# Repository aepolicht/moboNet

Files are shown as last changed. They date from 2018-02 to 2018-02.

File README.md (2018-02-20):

moboNet
=======

  This repo is a collection of elements contributing to one home automation project. It consists of analysis, schematics,
and software.

Notes
=====

Version 0.0.1
	Added Features:
		-Recall previous state from memory using EEPROM

	Bug Fixes:
		-Remove Flashes when receiving message

Version 0.0.2
	Added Features:
		-All communication now shall be over UDP packets

Version 0.0.3
	Changes:
		-Added notifications features to all devices
		-Added basic music detection and visualization code
			-Changes were also made to the hardware side of the music detection.
			 The low pass filter desired seems to have a cutoff right at 220 Hz.
		 	 Ideally this simple filter will consist of a 1 uF capacitor and a
		 	 7.5 kOhm resistor.
		-Implemented serial connection to bulb array to communicate with display 
		 projection from PC. Currently it checks serial, then homenet for any input
		 but if this proves to slow down the projection too much i may need a blocking
		 version where when serial is inbound all other code is ignored.
		-Changed to "FastSPI" library for communication with WS2801 LED strings
			-Also tried out an Adafruit library for this purpose but i found that
			 that library was blocking and took significantly more time to run
			 than the FastSPI library took.
			-FastSPI is non-blocking and takes around 300 uS to finish its write
		     otherwise overwriting while in progress produces undesirable effects.
	    -Implemented notifications for door knock however the whole system needs an
	     overhaul to simplify the process of [alarm device]->[base station]->[bulb clients]
	    -Implemented code for the door knock detector notifier.
	    
Version 0.0.4
	Note:
		I have begun to implement the music detection system. The basis for the whole system
		is contingent upon the frequency response of the low pass filter. I have chosen a simple
		filter with passband edge around 300 Hz. In this design a large gap between the passband 
		and the stop-band is desired because of how i plan to implement the software side of the
		music detection. Here is a rough graph of the frequency response:

			                    |H(w)| for LPF (1st order fc = 300Hz)
					  (dB)
					 0	|x x x x x x x x x x x 
					 	|                      x 
					-5	|                        x 
						|                          x
					-10	|                            x
						|                              x              
					-15	|                                x               
						|                                  x         
					-20	|                                    x           
						|                                      x         
					-25	|                                        x            
						|                                          x              
					-30	|                                            x                  
						|                                              x      
					-35	|                                                x      
						-------|----------|-----------|------------|----- Hz (log)
						0     10         100        1000         10000   

		The basis for the software side is having an understanding of the filters response
		and using this to determine whether or not the input signal is a Low, Mid or High.
		I am doing it this way to avoid any additional circuitry because i want a small
		package. It is easiest to detect the beat and very low frequencies because these are
		the largest in magnitude. I want a large gap between the passband and stop-band edges
		because i want to be able to detect other frequencies at attenuated magnitudes.
		To overcome the problem of detecting loud mids as a bass and other situations, i take
		an average of the last 64 samples as a reference. Given that reference the respective
		frequencies will then be function of the average unique to those frequency bands. To
		obtain a reference i sampled the desired frequency at different volumes IE different 
		values of the variable "ave". I then applied best fit lines and use them as cutoffs
		to determine which band a sample should be classified to. The best fits i have found
		are:
 
			Lows  (0-230Hz)   Threshold = 67*log(ave-1)-10
			Mids  (230-800Hz) Threshold = 25*log(ave-1)-5
			Highs (800+Hz)    Threshold = 12*log(ave-1)-5

		It is much more difficult to detect a high with this filter because signals higher than 
		800 Hz are attenuated more severely beginning with 800 Hz at -9 dB. The other method for
		doing this type of thing would be with a ~6000 Hz lpf and performing an FFT which i will
		do to see if its viable given the constraints.

		My preliminary DFT implementation with a 128 sample input and no special windowing takes around 2.5 seconds per DFT which is much too long. When N is 32, it takes about 155 mS.
		This would mean a sampling rate of T > 155 mS which a sampling frequency of less than
		6 Hz which is pretty much useless. The to attain a Nyquist frequency of a signal of 2000 Hz
		i need to have a sampling frequency of 4000 Hz which means the DFT finish in <250 uS. I 
		have found an FFT library for Arduino but it takes more than 600 uS to complete the FFT.
		This means i will continue with my previous method of implementing the lump spectral
		analysis.

TBD:
x-Add days support to android
x-Redesign notifications so that they are handled by base station
o-Setup music mode on all devices
x-Setup Door knock codes for base station and knocker
o-Setup Ambiance mode
o-Fix Android save and return functionality
o-Finish C# desktop application
o-Add notification options to base station and android options menu
o-Implement Groups on all devices

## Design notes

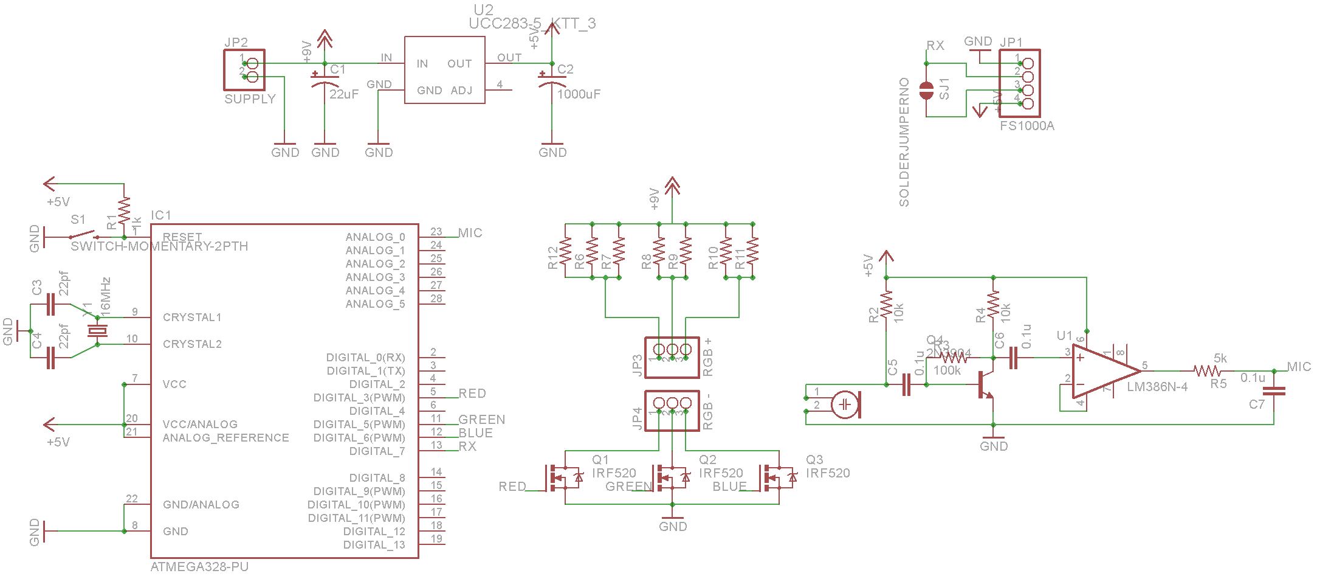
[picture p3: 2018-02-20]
Bulb_Node_PCB/Due/Schematic.png

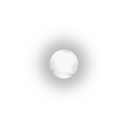
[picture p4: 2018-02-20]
PC_Application_Master Control/Master Control/Properties/Resources/Blank.png

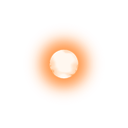
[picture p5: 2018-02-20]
PC_Application_Master Control/Master Control/Resources/Orange.png

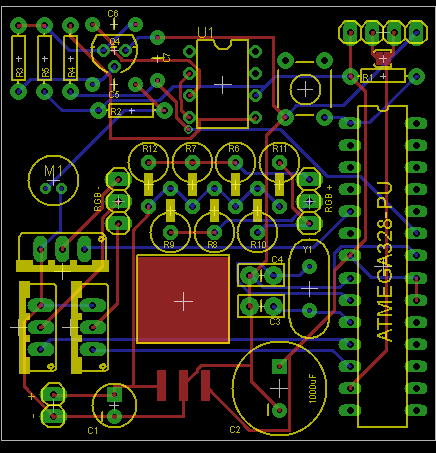
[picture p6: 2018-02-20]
Bulb_Node_PCB/Due/PCB2.png

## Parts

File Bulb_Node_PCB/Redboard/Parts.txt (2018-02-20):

Partlist

Exported from RedBoard-v21.sch at 2/24/2015 8:32:50 PM

EAGLE Version 7.1.0 Copyright (c) 1988-2014 CadSoft

Assembly variant: 

Part     Value                             Device                            Package                                Library               Sheet

AD                                         M06SMD-STRAIGHT-COMBO             1X06_SMD_STRAIGHT_COMBO                SparkFun              1
C1       0.1uF                             CAP0603-CAP                       0603-CAP                               SparkFun              1
C2       0.1uF                             CAP0603-CAP                       0603-CAP                               SparkFun              1
C3       10uF                              CAP_POL1206                       EIA3216                                SparkFun              1
C4       0.1uF                             CAP0603-CAP                       0603-CAP                               SparkFun              1
C5       47uF                              CAP_POLD                          PANASONIC_D                            SparkFun              1
C6       10uF                              CAP_POL1206                       EIA3216                                SparkFun              1
C7       1uF                               CAP0603-CAP                       0603-CAP                               SparkFun              1
C8       0.1uF                             CAP0603-CAP                       0603-CAP                               SparkFun              1
C9       47pF                              47PF-50V-5%(0603)                 0603-CAP                               SparkFun-Capacitors   1
C10      0.1uF                             CAP0603-CAP                       0603-CAP                               SparkFun              1
C12      0.1uF                             CAP0603-CAP                       0603-CAP                               SparkFun              1
C13      47pF                              47PF-50V-5%(0603)                 0603-CAP                               SparkFun-Capacitors   1
C14      0.1uF                             CAP0603-CAP                       0603-CAP                               SparkFun              1
C15      10uF                              CAP_POL1206                       EIA3216                                SparkFun-Capacitors   1
D1       MBRA140                           DIODE-SCHOTTKY_                   SMA-DIODE                              SparkFun              1
F1       500mA                             PTCSMD                            PTC-1206                               SparkFun              1
IC3      LM1117                            V_REG_LM1117ALT1                  SOT223-ALT1                            Testing               1
IOL                                        M08SMD-COMBO                      1X08_SMD_COMBINED                      SparkFun              1
J1       POWER_JACKOVERPASTE_REDBOARD_0603 POWER_JACKOVERPASTE_REDBOARD_0603 POWER_JACK_SMD_OVERPASTE_REDBOARD_0603 Testing               1
J2       ICSP                              AVR_SPI_PRG_6SMT_MALE             2X3_SMT_POSTS                          SparkFun-Connectors   1
JP2      M10SMD_COMBO                      M10SMD_COMBO                      1X10_SMD_COMBINED                      SparkFun-Connectors   1
JP10                                       M08SMD-COMBO                      1X08_SMD_COMBINED                      SparkFun-Connectors   1
LED1     Blue                              LED1206-NS                        LED-1206-NO_SILK                       SparkFun-LED          1
LED2     Green                             LED1206-NS                        LED-1206-NO_SILK                       SparkFun-LED          1
LED3     Red                               LED1206-NS                        LED-1206-NO_SILK                       SparkFun-LED          1
LED4     Yellow                            LED1206-NS                        LED-1206-NO_SILK                       SparkFun-LED          1
Q1       ZXMP6A13FTA                       MOSFET-PCHANNELSMD                SOT23-3                                SparkFun              1
Q2       2N7002PW                          MOSFET-NCHANNEL2N7002PW           SOT323                                 SparkFun-DiscreteSemi 1
R1       1k                                RESISTOR0603-RES                  0603-RES                               SparkFun              1
R2       1k                                RESISTOR0603-RES                  0603-RES                               SparkFun              1
R3       10k                               RESISTOR0603-RES                  0603-RES                               SparkFun              1
R4       10k                               RESISTOR0603-RES                  0603-RES                               SparkFun              1
R5       27                                RESISTOR0603-RES                  0603-RES                               SparkFun-Resistors    1
R6       1k                                RESISTOR0603-RES                  0603-RES                               SparkFun              1
R7       1k                                RESISTOR0603-RES                  0603-RES                               SparkFun              1
R8       1k                                RESISTOR0603-RES                  0603-RES                               SparkFun              1
R9       1k                                RESISTOR0603-RES                  0603-RES                               SparkFun              1
R10      27                                RESISTOR0603-RES                  0603-RES                               SparkFun-Resistors    1
R11      10k                               RESISTOR0603-RES                  0603-RES                               SparkFun              1
R12      10k                               RESISTOR0603-RES                  0603-RES                               SparkFun              1
R14      715                               RESISTOR0603-RES                  0603-RES                               SparkFun              1
R15      240                               RESISTOR0603-RES                  0603-RES                               SparkFun              1
S1       RESET                             TAC_SWITCHSMD                     TACTILE_SWITCH_SMD                     SparkFun              1
TP1      TP-3x5                            TEST-POINT3X5                     PAD.03X.05                             SparkFun-Passives     1
TP2      TP-3x5                            TEST-POINT3X5                     PAD.03X.05                             SparkFun-Passives     1
TP3      TP-3x5                            TEST-POINT3X5                     PAD.03X.05                             SparkFun-Passives     1
TP4      TP-3x5                            TEST-POINT3X5                     PAD.03X.05                             SparkFun-Passives     1
TP5      TP-3x5                            TEST-POINT3X5                     PAD.03X.05                             SparkFun-Passives     1
TP6      TP-3x5                            TEST-POINT3X5                     PAD.03X.05                             SparkFun-Passives     1
U$13     USB-MINIB-5PIN                    USB-MINIB-5PIN                    USB-MINIB                              SparkFun-Connectors   1
U1       FT231XS                           FT231XS                           SSOP20_L                               SparkFun-DigitalIC    1
U2       MIC5205                           V_REG_LDOSMD                      SOT23-5                                SparkFun              1
U3       ATMEGA328                         ATMEGA168                         TQFP32-08                              SparkFun              1
Y1       16MHz                             RESONATORSMD                      RESONATOR-SMD                          SparkFun-FreqCtrl     1

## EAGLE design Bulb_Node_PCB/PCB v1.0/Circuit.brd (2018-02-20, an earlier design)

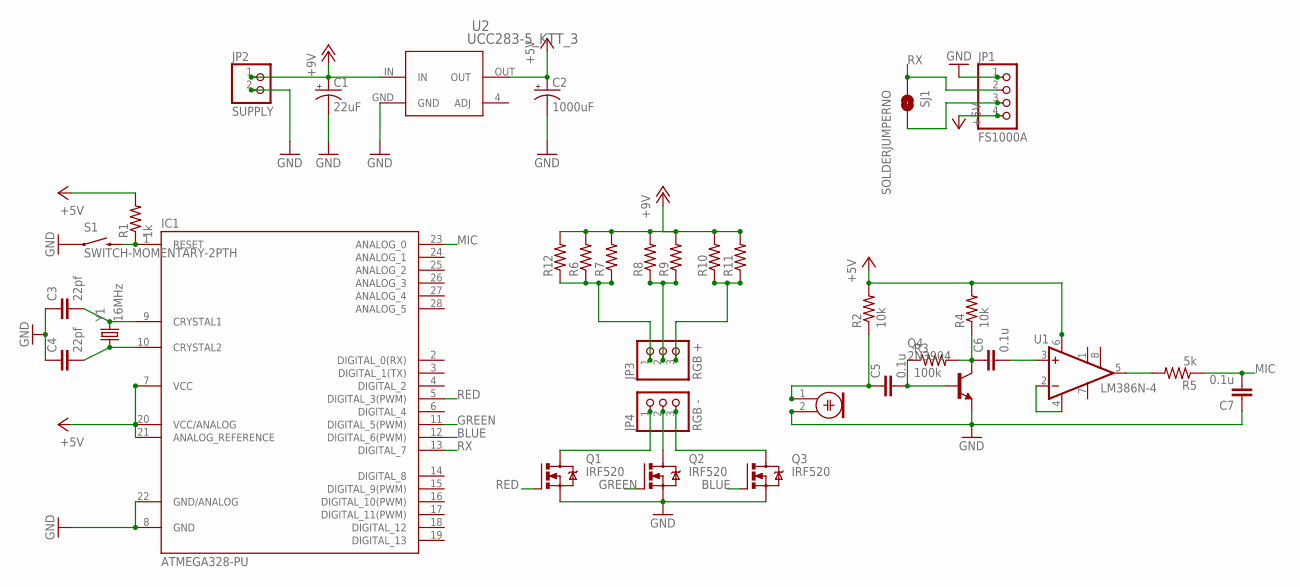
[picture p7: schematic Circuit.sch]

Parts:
C1: 22uF; CPOL-RADIAL-10UF-25V
C2: 1000uF; CPOL-RADIAL-1000UF-25V
C3, C4: 22pf; CAP-PTH-SMALL-KIT
C5, C6, C7: 0.1u; CAP-PTH-5MM
IC1: ATMEGA328-PU; DIL28-3
JP1: FS1000A; 1X04
JP2: SUPPLY; 1X02
JP3: RGB +; 1X03
JP4: RGB -; 1X03
M1: MIC; WM-62PC/62PK
Q1, Q2, Q3: IRF520; TO220BV
Q4: 2N3904; TO92
R1: 1k; AXIAL-0.3EZ
R2, R4: 10k; AXIAL-0.3EZ
R3: 100k; AXIAL-0.3EZ
R5: 5k; AXIAL-0.3EZ
R6, R7, R8, R9, R10, R11, R12: R-US_0613/5V; P0613V
S1: SWITCH-MOMENTARY-2PTH; TACTILE-PTH
SJ1: SOLDERJUMPERNO; SJ_2S-NO
U1: LM386N-4; DIL08
U2: UCC283-5_KTT_3; KTT3_6P22X6P6
Y1: 16MHz; HC49US

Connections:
+5V: C2.1 (+), IC1.7 (VCC), IC1.20 (VCC/ANALOG), IC1.21 (ANALOG_REFERENCE), JP1.4, R1.P$2 (2), R2.P$2 (2), R4.P$2 (2), U1.6 (VS), U2.OUT
+12V: C1.1 (+), JP2.1, R6.2, R7.2, R8.2, R9.2, R10.2, R11.2, R12.2, U2.IN
BLUE: IC1.12 (DIGITAL_6(PWM)), Q3.G
GND: C1.2 (-), C2.2 (-), C3.1, C4.1, C7.1, IC1.8 (GND), IC1.22 (GND/ANALOG), JP1.1, JP2.2, M1.2, Q1.S, Q2.S, Q3.S, Q4.3 (E), S1.1, U2.GND
GREEN: IC1.11 (DIGITAL_5(PWM)), Q2.G
MIC: C7.2, IC1.23 (ANALOG_0), R5.P$1 (1)
unnamed: JP1.3, SJ1.2
unnamed: C3.2, IC1.9 (CRYSTAL1), Y1.2
unnamed: C4.2, IC1.10 (CRYSTAL2), Y1.1
unnamed: IC1.1 (RESET), R1.P$1 (1), S1.3 (2)
unnamed: JP4.1, Q1.D
unnamed: JP4.2, Q2.D
unnamed: JP4.3, Q3.D
unnamed: C5.2, Q4.2 (B), R3.P$1 (1)
unnamed: C5.1, M1.1, R2.P$1 (1)
unnamed: C6.1, Q4.1 (C), R3.P$2 (2), R4.P$1 (1)
unnamed: R5.P$2 (2), U1.5 (OUT)
unnamed: U1.2 (-IN), U1.4 (GND)
unnamed: JP3.1, R6.1, R7.1, R12.1
unnamed: JP3.2, R8.1, R9.1
unnamed: JP3.3, R10.1, R11.1
unnamed: C6.2, U1.3 (+IN)
RED: IC1.5 (DIGITAL_3(PWM)), Q1.G
RX: IC1.13 (DIGITAL_7), JP1.2, SJ1.1

Board: 2 copper layers, 34 parts (0 on the bottom side), 24 nets, no tracks yet.

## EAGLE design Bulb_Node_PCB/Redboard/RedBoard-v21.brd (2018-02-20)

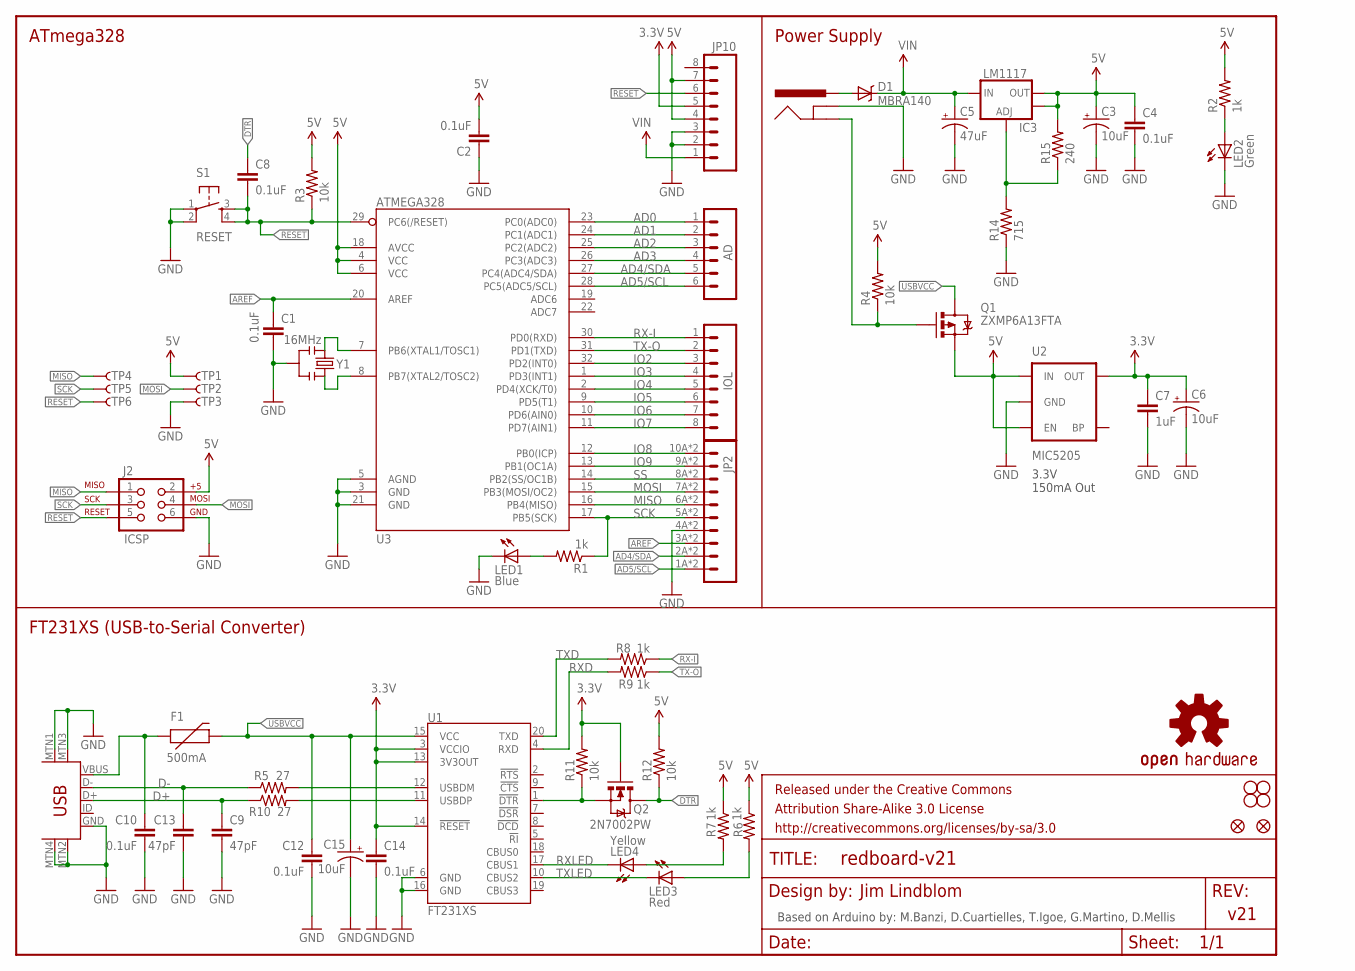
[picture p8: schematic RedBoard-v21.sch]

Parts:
AD: M06SMD-STRAIGHT-COMBO; 1X06_SMD_STRAIGHT_COMBO
C1, C2, C4, C8, C10, C12, C14: 0.1uF; 0603-CAP
C3, C6, C15: 10uF; EIA3216
C5: 47uF; PANASONIC_D
C7: 1uF; 0603-CAP
C9, C13: 47pF; 0603-CAP
D1: MBRA140; SMA-DIODE
F1: 500mA; PTC-1206
FRAME2: FRAME-LETTER; CREATIVE_COMMONS
IC3: LM1117; SOT223-ALT1
IOL: M08SMD-COMBO; 1X08_SMD_COMBINED
J1: POWER_JACKOVERPASTE_REDBOARD_0603; POWER_JACK_SMD_OVERPASTE_REDBOARD_0603
J2: ICSP; 2X3_SMT_POSTS
JP2: M10SMD_COMBO; 1X10_SMD_COMBINED
JP3, JP4, JP5, JP6: STAND-OFF
JP8, JP9: FIDUCIAL1X2; FIDUCIAL-1X2
JP10: M08SMD-COMBO; 1X08_SMD_COMBINED
LED1: Blue; LED-1206-NO_SILK
LED2: Green; LED-1206-NO_SILK
LED3: Red; LED-1206-NO_SILK
LED4: Yellow; LED-1206-NO_SILK
Q1: ZXMP6A13FTA; SOT23-3
Q2: 2N7002PW; SOT323
R1, R2, R6, R7, R8, R9: 1k; 0603-RES
R3, R4, R11, R12: 10k; 0603-RES
R5, R10: 27; 0603-RES
R14: 715; 0603-RES
R15: 240; 0603-RES
S1: RESET; TACTILE_SWITCH_SMD
TP1, TP2, TP3, TP4, TP5, TP6: TP-3x5; PAD.03X.05
U1: FT231XS; SSOP20_L
U2: MIC5205; SOT23-5
U3: ATMEGA328; TQFP32-08
U$13: USB-MINIB-5PIN; USB-MINIB
U$16: OSHW-LOGOS; OSHW-LOGO-S
Y1: 16MHz; RESONATOR-SMD

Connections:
3.3V: C6.A (+), C7.1, C14.1, JP10.5, Q2.1 (G), R11.2, U1.3 (VCCIO), U1.13 (3V3OUT), U1.14 (!RESET), U2.5 (OUT)
5V: C2.2, C3.A (+), C4.1, IC3.2 (OUT), IC3.4 (OUT), J2.2, JP10.4, JP10.7, Q1.2 (S), R2.2, R3.2, R4.2, R6.1, R7.1, R12.2, R15.2, TP1.P$1, U2.1 (IN), U2.3 (EN), U3.4 (VCC), U3.6 (VCC), U3.18 (AVCC)
AD0: AD.1, U3.23 (PC0(ADC0))
AD1: AD.2, U3.24 (PC1(ADC1))
AD2: AD.3, U3.25 (PC2(ADC2))
AD3: AD.4, U3.26 (PC3(ADC3))
AD4/SDA: AD.5, JP2.2A (2), JP2.2B (2), U3.27 (PC4(ADC4/SDA))
AD5/SCL: AD.6, JP2.1A (1), JP2.1B (1), U3.28 (PC5(ADC5/SCL))
AREF: C1.1, JP2.3A (3), JP2.3B (3), U3.20 (AREF)
D+: C9.1, R10.1, U$13.D+
D-: C13.1, R5.1, U$13.D-
DTR: C8.1, Q2.3 (D), R12.1
GND: C1.2, C2.1, C3.C (-), C4.2, C5.-, C6.C (-), C7.2, C9.2, C10.2, C12.2, C13.2, C14.2, C15.C (-), J1.GND (GNDBREAK), J2.6, JP2.4A (4), JP2.4B (4), JP10.2, JP10.3, LED1.C, LED2.C, R14.1, S1.1, S1.2, TP3.P$1, U1.6 (GND), U1.16 (GND), U2.2 (GND), U3.3 (GND), U3.5 (AGND), U3.21 (GND), U$13.GND, U$13.MTN1 (MTN2), U$13.MTN2 (MTN3), U$13.MTN3 (MTN1), U$13.MTN4, Y1.2
INSERT: J1.P$4 (GND), Q1.1 (G), R4.1
IO2: IOL.3, U3.32 (PD2(INT0))
IO3: IOL.4, U3.1 (PD3(INT1))
IO4: IOL.5, U3.2 (PD4(XCK/T0))
IO5: IOL.6, U3.9 (PD5(T1))
IO6: IOL.7, U3.10 (PD6(AIN0))
IO7: IOL.8, U3.11 (PD7(AIN1))
IO8: JP2.10A (10), JP2.10B (10), U3.12 (PB0(ICP))
IO9: JP2.9A (9), JP2.9B (9), U3.13 (PB1(OC1A))
MISO: J2.1, JP2.6A (6), JP2.6B (6), TP4.P$1, U3.16 (PB4(MISO))
MOSI: J2.4, JP2.7A (7), JP2.7B (7), TP2.P$1, U3.15 (PB3(MOSI/OC2))
unnamed: LED1.A, R1.2
unnamed: LED2.A, R2.1
unnamed: U3.7 (PB6(XTAL1/TOSC1)), Y1.1
unnamed: U3.8 (PB7(XTAL2/TOSC2)), Y1.3
unnamed: R5.2, U1.12 (USBDM)
unnamed: R10.2, U1.11 (USBDP)
unnamed: LED3.A, R6.2
unnamed: LED4.A, R7.2
unnamed: Q2.2 (S), R11.1, U1.1 (!DTR)
unnamed: IC3.1 (ADJ), R14.2, R15.1
PWRIN: D1.A, J1.VIN0 (PWR)
RESET: C8.2, J2.5, JP10.6, R3.1, S1.3, S1.4, TP6.P$1, U3.29 (PC6(/RESET))
RX-I: IOL.1, R8.1, U3.30 (PD0(RXD))
RXD: R9.2, U1.4 (RXD)
RXLED: LED4.C, U1.17 (CBUS1)
SCK: J2.3, JP2.5A (5), JP2.5B (5), R1.1, TP5.P$1, U3.17 (PB5(SCK))
SS: JP2.8A (8), JP2.8B (8), U3.14 (PB2(SS/OC1B))
TX-O: IOL.2, R9.1, U3.31 (PD1(TXD))
TXD: R8.2, U1.20 (TXD)
TXLED: LED3.C, U1.10 (CBUS2)
USBVCC: C12.1, C15.A (+), F1.2, Q1.3 (D), U1.15 (VCC)
VIN: C5.+, D1.C, IC3.3 (IN), JP10.1
VUSB: C10.1, F1.1, U$13.VBUS

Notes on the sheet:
Power Supply
ATmega328
FT231XS (USB-to-Serial Converter)
Based on Arduino by: M.Banzi, D.Cuartielles, T.Igoe, G.Martino, D.Mellis
3.3V 150mA Out
Jim Lindblom
v21

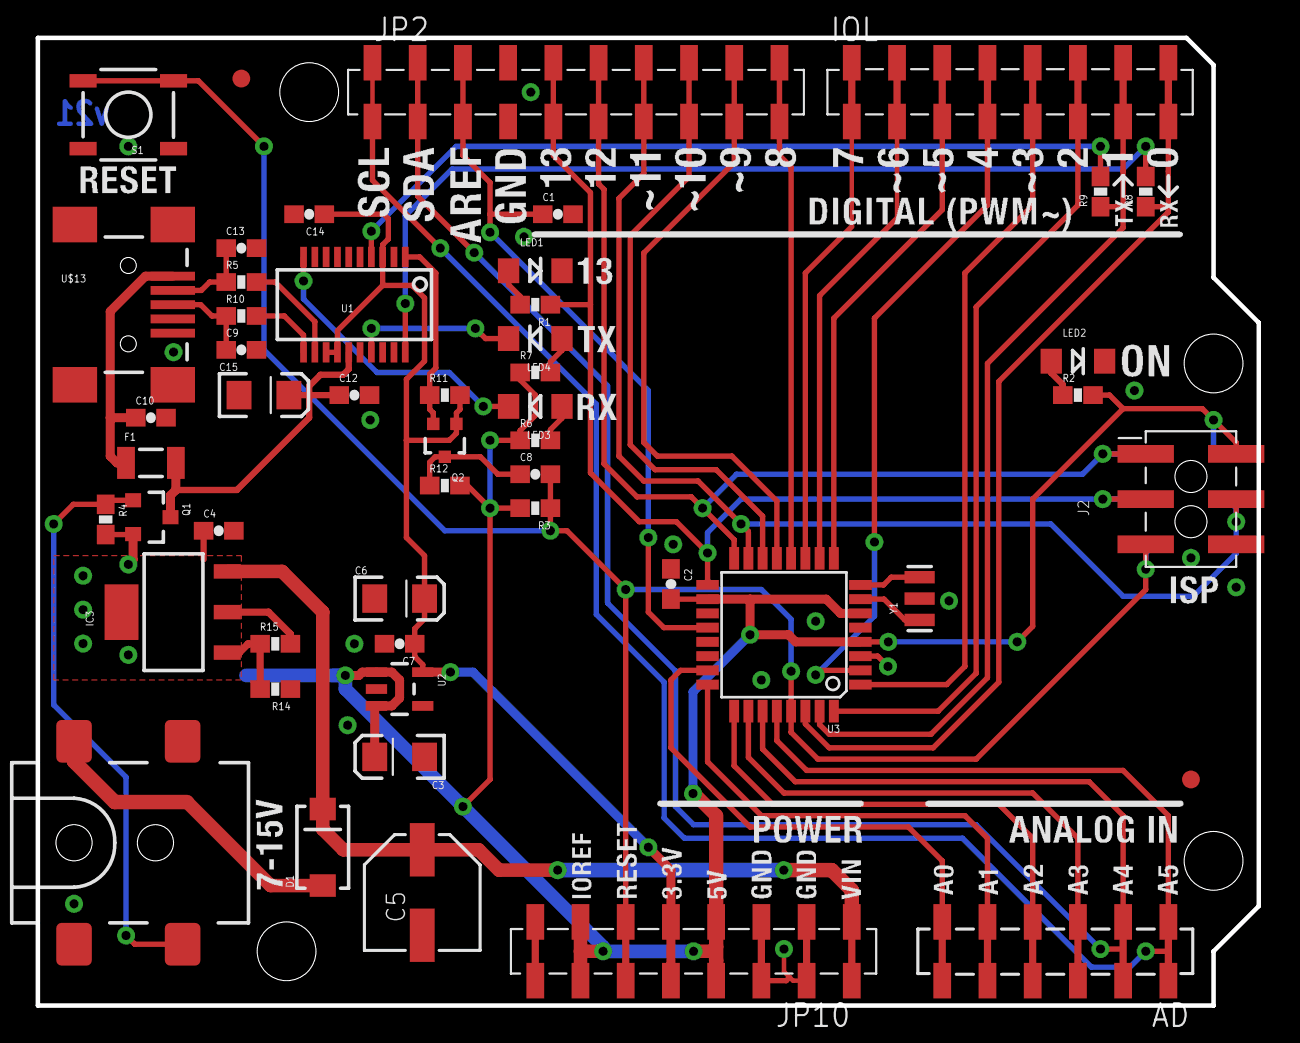
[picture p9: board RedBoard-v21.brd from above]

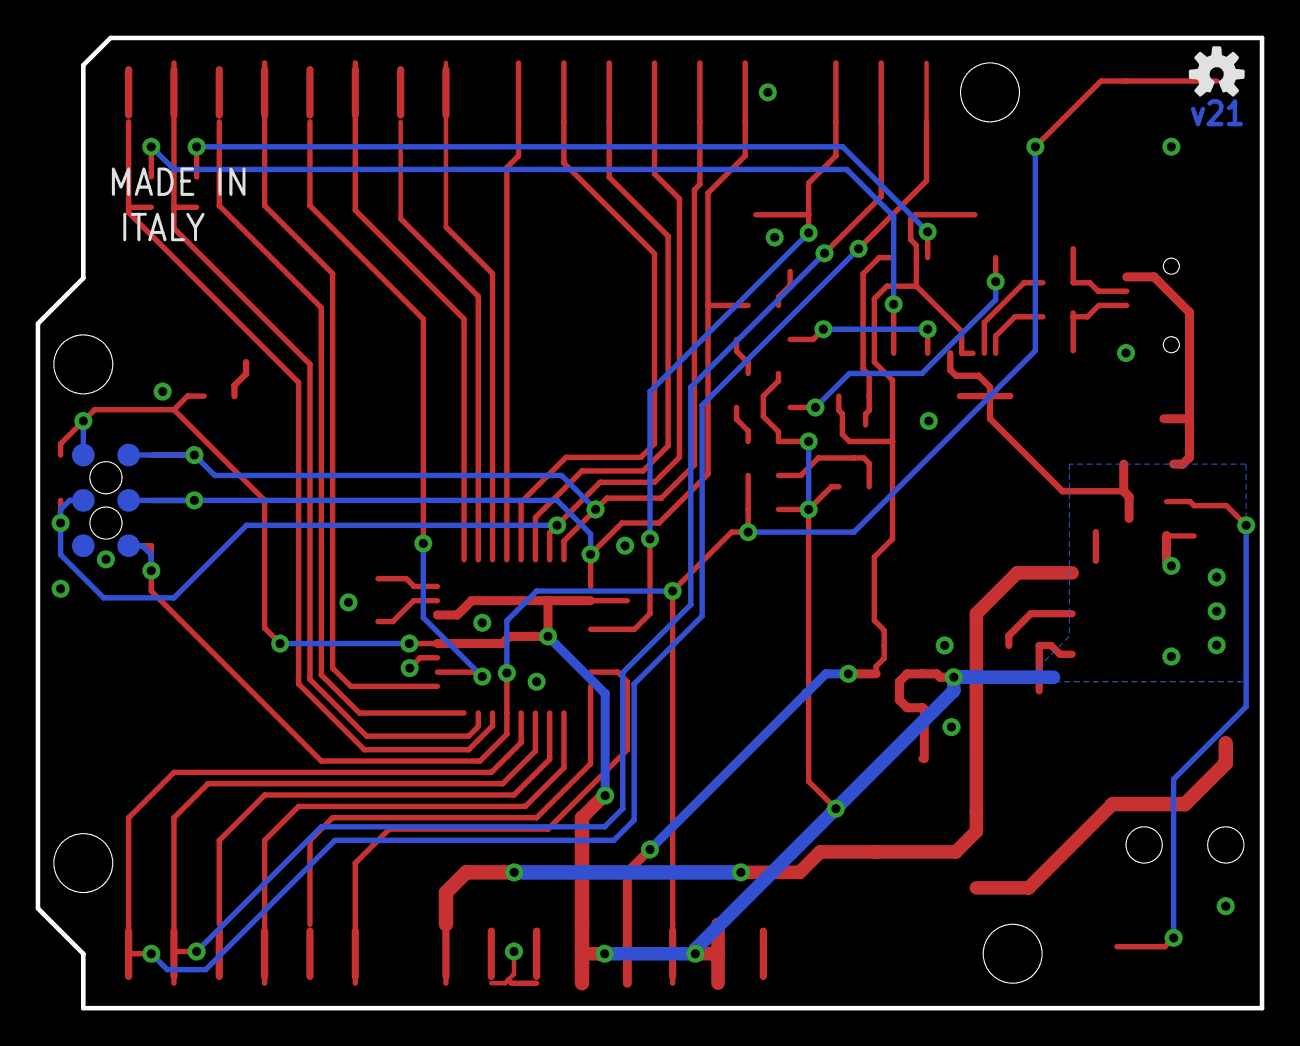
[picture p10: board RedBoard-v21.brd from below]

Board: 2 copper layers, 68.6 x 54.4 mm, 63 parts (7 on the bottom side), 47 nets.

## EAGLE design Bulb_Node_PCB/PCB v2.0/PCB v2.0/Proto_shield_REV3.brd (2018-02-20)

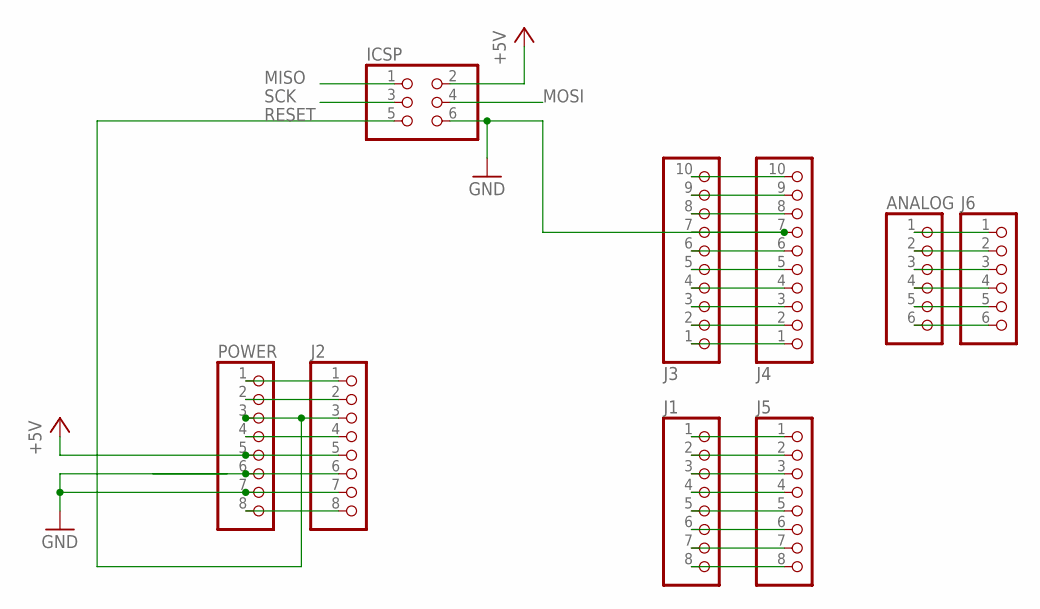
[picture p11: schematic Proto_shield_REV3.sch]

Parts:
ANALOG: PINHD-1X6; 1X06
ICSP: PINHD-2X3; 2X03
J1, J2, J5: PINHD-1X8TH; 1X08-TH
J3, J4: PINHD-1X10TH; 1X10-TH
J6: PINHD-1X6; 1X06
POWER: PINHD-1X8TH; 1X08-TH

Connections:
+5V: ICSP.2, J2.5, POWER.5
+9V: J2.8, POWER.8
GND: ICSP.6, J2.7, J3.7, J4.7, POWER.7
MISO: ICSP.1
MOSI: ICSP.4
unnamed: J3.6, J4.6
unnamed: J3.1, J4.1
unnamed: J3.4, J4.4
unnamed: J3.5, J4.5
unnamed: J3.2, J4.2
unnamed: J3.3, J4.3
unnamed: J1.1, J5.1
unnamed: J1.2, J5.2
unnamed: J1.3, J5.3
unnamed: J1.4, J5.4
unnamed: J1.5, J5.5
unnamed: J1.6, J5.6
unnamed: J1.7, J5.7
unnamed: J1.8, J5.8
unnamed: ANALOG.1, J6.1
unnamed: ANALOG.2, J6.2
unnamed: ANALOG.3, J6.3
unnamed: ANALOG.4, J6.4
unnamed: ANALOG.5, J6.5
unnamed: ANALOG.6, J6.6
unnamed: J2.6, POWER.6
unnamed: J2.2, POWER.2
unnamed: J2.1, POWER.1
unnamed: J3.9, J4.9
unnamed: J3.10, J4.10
unnamed: J3.8, J4.8
unnamed: J2.4, POWER.4
RESET: ICSP.5, J2.3, POWER.3
SCK: ICSP.3

Board: 2 copper layers, 9 parts (0 on the bottom side), 31 nets, no tracks yet.

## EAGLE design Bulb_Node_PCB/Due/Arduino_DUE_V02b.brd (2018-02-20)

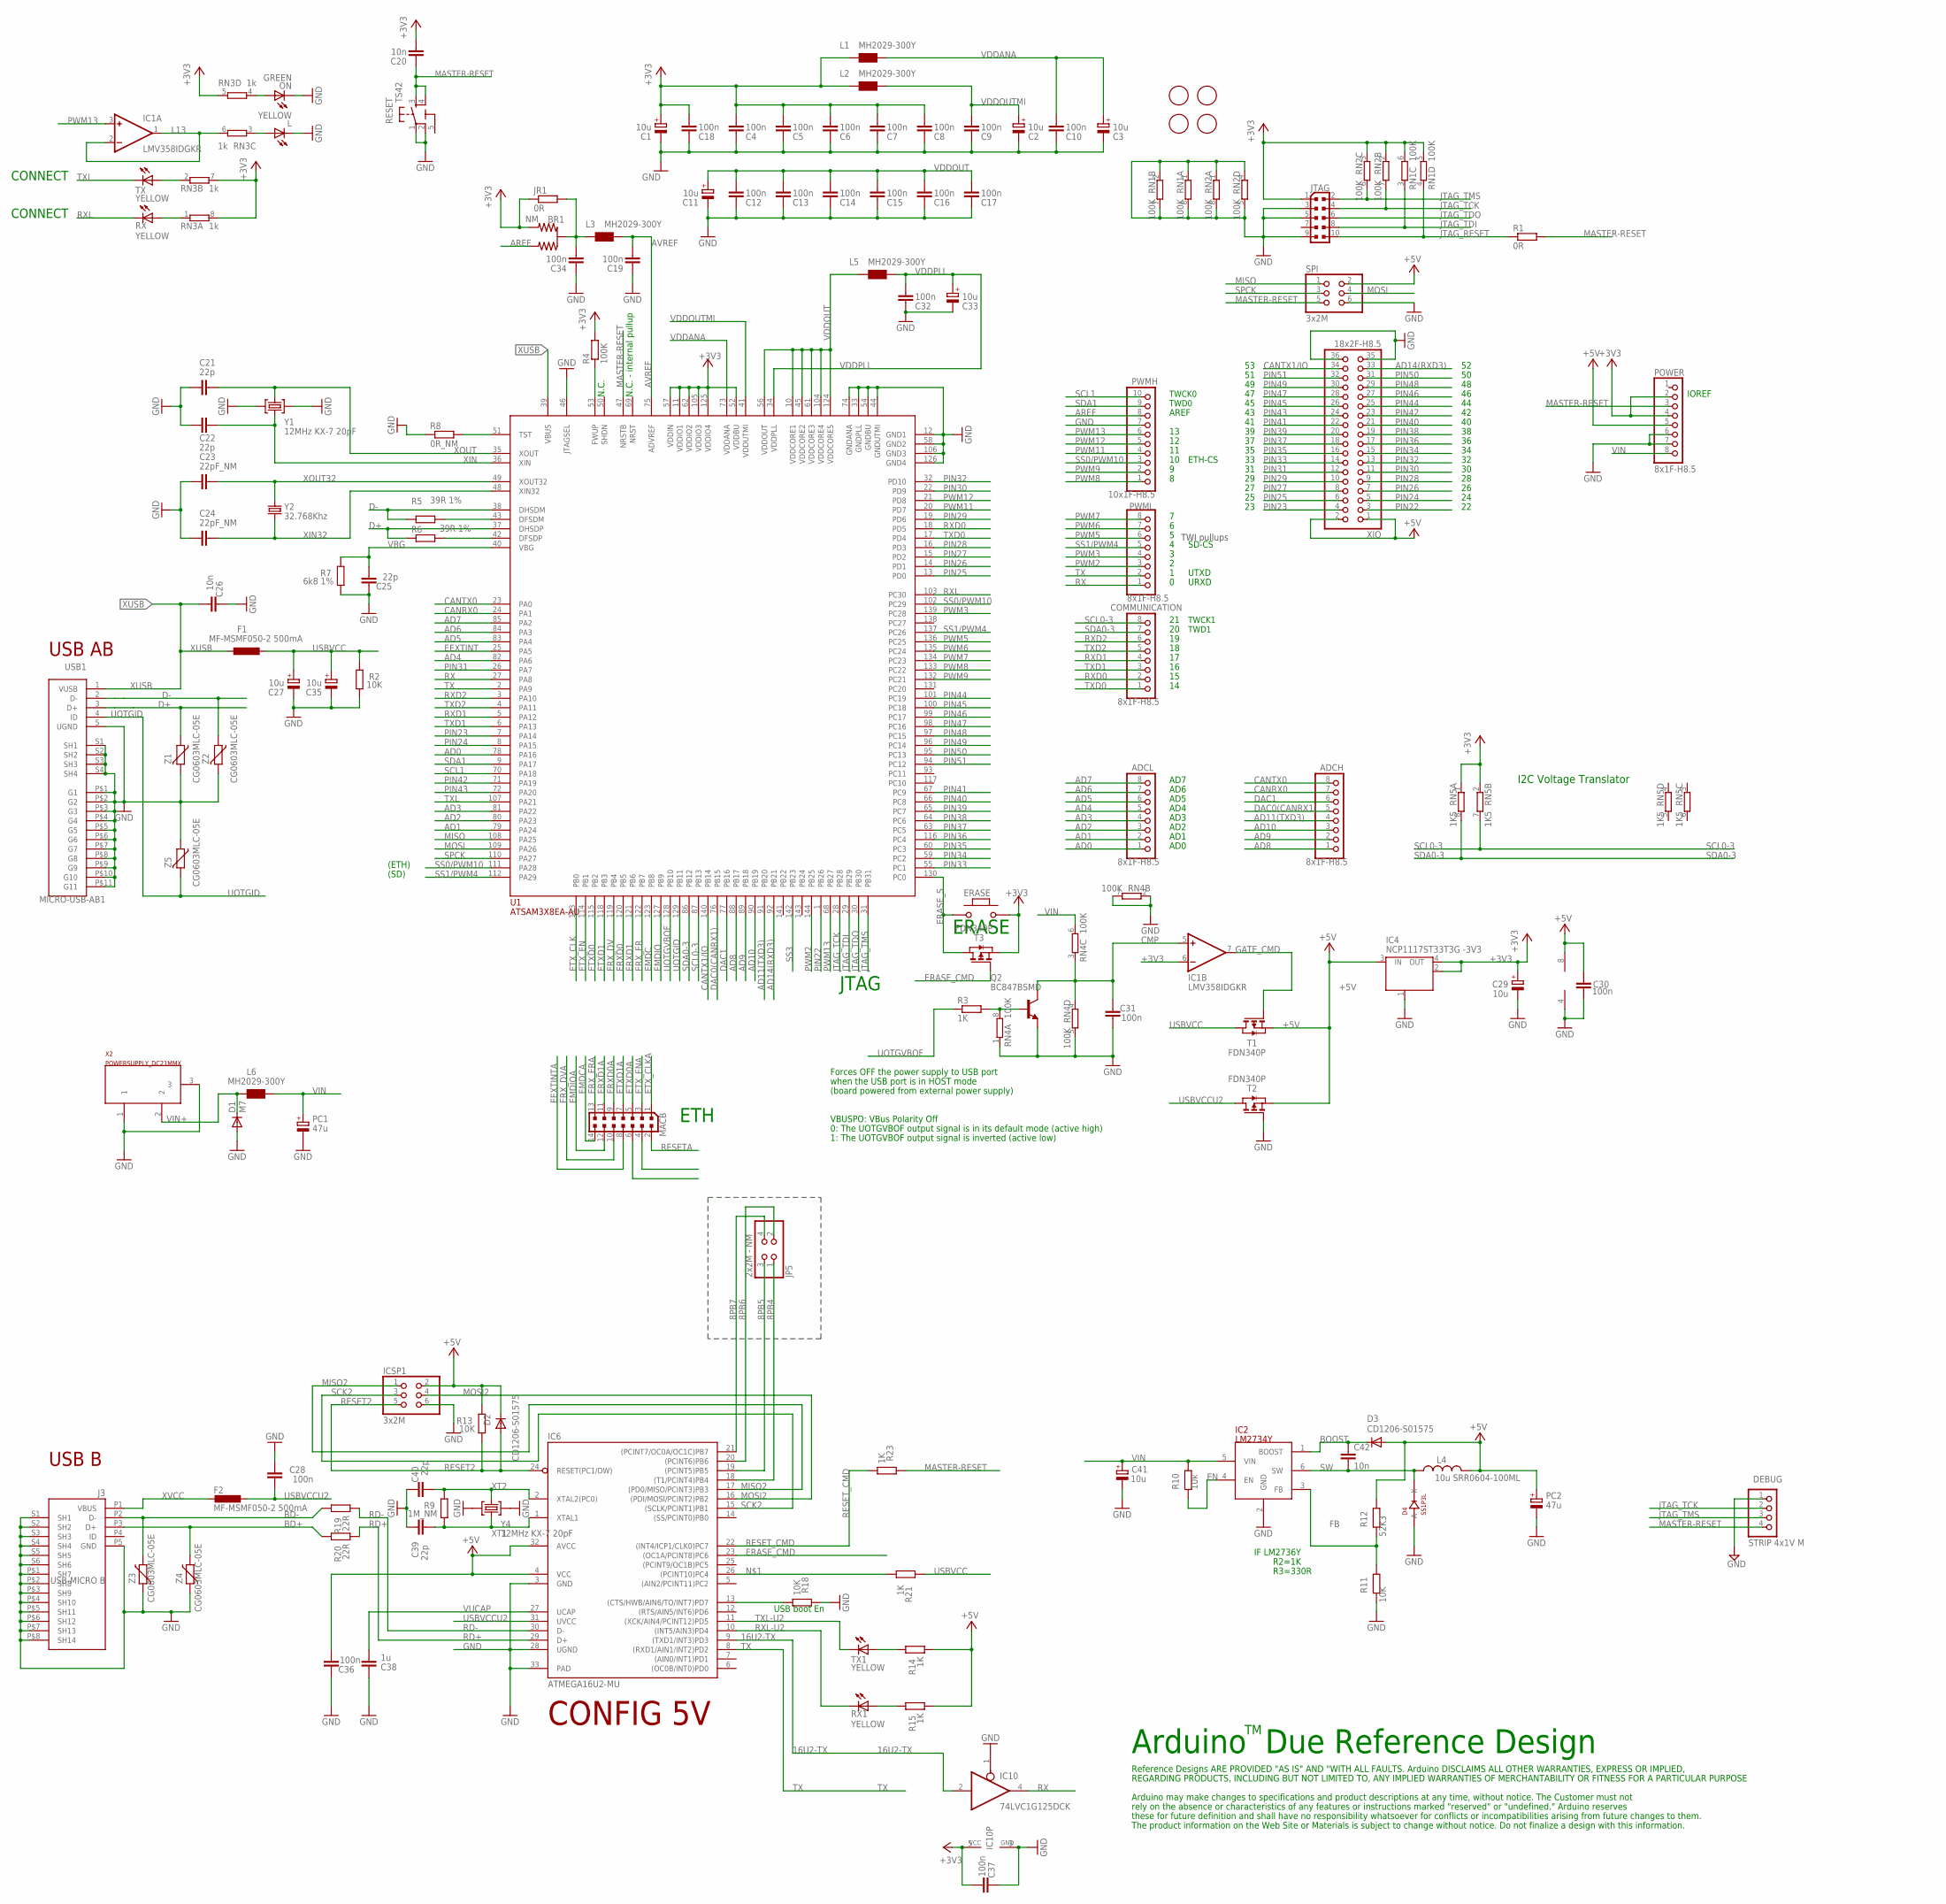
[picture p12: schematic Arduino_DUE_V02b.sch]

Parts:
ADCH: 8x1F-H8.5; 1X08
ADCL: 8x1F-H8.5; 1X08
BR1: NM; J0402
C1, C2, C3, C11, C27, C29, C33, C35, C41: 10u; SMC_B
C4, C5, C6, C7, C8, C9, C10, C12, C13, C14, C15, C16, C17, C18, C19, C28, C30, C31, C32, C34, C36, C37: 100n; C0402
C20, C26: 10n; C0402
C21, C22, C25, C39, C40: 22p; C0402
C23, C24: 22pF_NM; C0402
C38: 1u; C0402
C42: 10n; C0603-ROUND
COMMUNICATION: 8x1F-H8.5; 1X08
D1: M7; SMB
D2, D3: CD1206-S01575; MINIMELF
D4: SS1P3L; DO220AAL
DEBUG: STRIP 4x1V M; 1X04
ERASE: MYSMD_PB157; SMD_157SW
F1, F2: MF-MSMF050-2 500mA; L1812
FID1, FID2, FID3, FID4: FIDUCIALMOUNT; FIDUCIA-MOUNT
IC1: LMV358IDGKR; MSOP08
IC2: LM2734Y; SOT23-6
IC4: NCP1117ST33T3G -3V3; SOT223
IC6: ATMEGA16U2-MU; MLF32
IC10: 74LVC1G125DCK; SC70-5
ICSP1: 3x2M; 2X03
J3: USB-MICRO B; CON2_USB_MICRO_B_AT
JP5: 2x2M - NM; 2X02
JR1: 0R; R0402
JTAG: PINHEAD_PINHD-2X5PASSO127; PINHEAD_2X05_127
L: YELLOW; CHIP-LED0805
L1, L2, L3, L5, L6: MH2029-300Y; 0805
L4: 10u SRR0604-100ML; SRR0604
MACB: PINHEAD_PINHD-2X7PASSO127; PINHEAD_2X07_127
ON: GREEN; CHIP-LED0805
PC1, PC2: 47u; PANASONIC_D
POWER: 8x1F-H8.5; 1X08
PWMH: 10x1F-H8.5; 1X10
PWML: 8x1F-H8.5; 1X08
Q2: BC847BSMD; SOT23
R1: 0R; R0402
R2, R13, R18: 10K; R0402
R3, R14, R15, R21, R23: 1K; R0402
R4: 100K; R0402
R5, R6: 39R 1%; R0402
R7: 6k8 1%; R0603-ROUND
R8: 0R_NM; R0402
R9: 1M_NM; R0402
R10: 10k; R0402
R11: 10K; R0603-ROUND
R12: 52K3; R0603-ROUND
R19, R20: 22R; R0402
RESET: TS42
RN1, RN2, RN4: 100K; CAT16
RN3: 1k; CAY16
RN5: 1K5; CAT16
RX, RX1: YELLOW; CHIP-LED0805
SPI: 3x2M; 2X03
T1, T2, T3: FDN340P; SOT-23
TX, TX1: YELLOW; CHIP-LED0805
U1: ATSAM3X8EA-AU; LQFP144
USB1: MICRO-USB-AB1; MCR-AB1-S-RA-SMT
X2: POWERSUPPLY_DC21MMX; POWERSUPPLY_DC-21MM
XIO: 18x2F-H8.5; 2X18
Y1, Y4: 12MHz KX-7 20pF; CRYSTAL-3.2-2.5
Y2: 32.768Khz; RESONATOR_EPSON_FC_145
Z1, Z2, Z3, Z4, Z5: CG0603MLC-05E; CT/CN0603

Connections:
5-GND: RESET.5 (5-GND)
8PB4: IC6.18 ((T1/PCINT4)PB4), JP5.1
8PB5: IC6.19 ((PCINT5)PB5), JP5.3
8PB6: IC6.20 ((PCINT6)PB6), JP5.2
8PB7: IC6.21 ((PCINT7/OC0A/OC1C)PB7), JP5.4
16U2-TX: IC6.9 ((TXD1/INT3)PD3), IC10.2 (I)
+3V3: BR1.3 (2), C1.+, C4.2, C5.2, C6.2, C7.2, C8.2, C18.2, C20.2, C29.+, C37.1, ERASE.1, IC1.6 (-IN), IC4.2 (OUT), IC4.4 (OUT), IC10.5 (VCC), JR1.1, JTAG.1, L1.1, L2.1, POWER.2, POWER.4, R4.2, RN1.5 (2), RN1.6 (2), RN2.2 (1), RN2.3 (1), RN3.5 (2), RN3.7 (2), RN3.8 (2), RN5.1, RN5.2 (1), T3.2 (S), U1.11 (VDDIO1), U1.52 (VDDBU), U1.57 (VDDIN), U1.62 (VDDIO2), U1.105 (VDDIO3), U1.125 (VDDIO4)
+5V: C30.2, C36.1, D2.C, D3.A, IC1.8 (V+), IC4.3 (IN), IC6.4 (VCC), IC6.32 (AVCC), ICSP1.2, L4.P$2 (2), PC2.+, POWER.5, R12.1, R13.2, R14.1, R15.1, SPI.2, T1.2 (S), T2.2 (S), XIO.1, XIO.2
AD0: ADCL.1, U1.78 (PA16)
AD1: ADCL.2, U1.79 (PA24)
AD2: ADCL.3, U1.80 (PA23)
AD3: ADCL.4, U1.81 (PA22)
AD4: ADCL.5, U1.82 (PA6)
AD5: ADCL.6, U1.83 (PA4)
AD6: ADCL.7, U1.84 (PA3)
AD7: ADCL.8, U1.85 (PA2)
AD8: ADCH.1, U1.88 (PB17)
AD9: ADCH.2, U1.89 (PB18)
AD10: ADCH.3, U1.90 (PB19)
AD11(TXD3): ADCH.4, U1.91 (PB20)
AD14(RXD3): U1.92 (PB21), XIO.33
AREF: BR1.1, PWMH.8
AVREF: C19.2, L3.2, U1.75 (ADVREF)
AVREFL: BR1.2 (C), C34.2, JR1.2, L3.1
BD+: J3.P3 (D+), R20.2, Z4.2
BD-: J3.P2 (D-), R19.2, Z3.2
BOOST: C42.1, D3.C, IC2.1 (BOOST)
CANRX0: ADCH.7, U1.24 (PA1)
CANTX0: ADCH.8, U1.23 (PA0)
CANTX1/IO: U1.140 (PB14), XIO.34
CMP: C31.2, IC1.5 (+IN), Q2.3 (C), RN4.3 (1), RN4.4 (1)
D+: R6.1, U1.37 (DHSDP), USB1.3 (D+), Z1.1
D-: R5.1, U1.38 (DHSDM), USB1.2 (D-), Z2.1
DAC0(CANRX1): ADCH.5, U1.76 (PB15)
DAC1: ADCH.6, U1.77 (PB16)
DTR: IC6.13 ((CTS/HWB/AIN6/TO/INT7)PD7), R18.1
EEXTINT: U1.25 (PA5)
EEXTINTA: MACB.8
EMDC: U1.123 (PB8)
EMDCA: MACB.14
EMDIO: U1.127 (PB9)
EMDIOA: MACB.12 (13)
EN: IC2.4 (EN), R10.2
ERASE_CMD: IC6.23 ((OC1A/PCINT8)PC6), T3.3 (G)
ERASE_S: ERASE.2, T3.1 (D), U1.130 (PC0)
ERXD0: U1.120 (PB5)
ERXD0A: MACB.9
ERXD1: U1.121 (PB6)
ERXD1A: MACB.11
ERX_DV: U1.119 (PB4)
ERX_DVA: MACB.10
ERX_ER: U1.122 (PB7)
ERX_ERA: MACB.13 (12)
ETXD0: U1.115 (PB2)
ETXD0A: MACB.5
ETXD1: U1.118 (PB3)
ETXD1A: MACB.7
ETX_CLK: U1.113 (PB0)
ETX_CLKA: MACB.1
ETX_EN: U1.114 (PB1)
ETX_ENA: MACB.3
FB: IC2.3 (FB), R11.1, R12.2
GATE_CMD: IC1.7 (OUT), T1.3 (G)
GND: C1.-, C2.-, C3.-, C4.1, C5.1, C6.1, C7.1, C8.1, C9.1, C10.1, C11.-, C12.1, C13.1, C14.1, C15.1, C16.1, C17.1, C18.1, C19.1, C21.2, C22.2, C23.2, C24.2, C25.2, C26.2, C27.-, C28.2, C29.-, C30.1, C31.1, C32.1, C33.-, C34.1, C35.-, C36.2, C37.2, C38.2, C39.2, C40.2, C41.-, D1.A, D4.P$2 (A), DEBUG.1, IC1.4 (V-), IC2.2 (GND), IC4.1 (GND/ADJ), IC6.3 (GND), IC6.28 (UGND), IC6.33 (PAD), IC10.1 (OE), IC10.3 (GND), ICSP1.6, J3.P5 (GND), J3.P$1 (SH7), J3.P$2 (SH8), J3.P$3 (SH9), J3.P$4 (SH10), J3.P$5 (SH11), J3.P$6 (SH12), J3.P$7 (SH13), J3.P$8 (SH14), J3.S1 (SH1), J3.S2 (SH2), J3.S3 (SH3), J3.S4 (SH4), J3.S5 (SH5), J3.S6 (SH6), JTAG.3, JTAG.5, JTAG.9, L.C, ON.C, PC1.-, PC2.-, POWER.6, POWER.7, PWMH.7, Q2.2 (E), R2.1, R7.1, R8.1, R11.2, R18.2, RESET.1, RESET.2, RN1.1, RN1.2 (1), RN1.7 (2), RN1.8 (2), RN2.1, RN2.4 (1), RN2.5 (2), RN2.8 (2), RN4.1, RN4.2 (1), RN4.5 (2), RN4.7 (2), SPI.6, T2.3 (G), U1.12 (GND1), U1.33 (GNDPLL), U1.44 (GNDUTMI), U1.46 (JTAGSEL), U1.54 (GNDBU), U1.58 (GND2), U1.74 (GNDANA), U1.106 (GND3), U1.126 (GND4), USB1.5 (UGND), USB1.P$1 (G1), USB1.P$2 (G2), USB1.P$3 (G3), USB1.P$4 (G4), USB1.P$5 (G5), USB1.P$6 (G6), USB1.P$7 (G7), USB1.P$8 (G8), USB1.P$9 (G9), USB1.P$10 (G10), USB1.P$11 (G11), USB1.S1 (SH1), USB1.S2 (SH2), USB1.S3 (SH3), USB1.S4 (SH4), X2.1, X2.3, XIO.35, XIO.36, Y1.2 (GND), Y1.4 (GND), Y4.2 (GND), Y4.4 (GND), Z1.2, Z2.2, Z3.1, Z4.1, Z5.1
JTAG_RESET: JTAG.10, R1.1, RN1.4 (1)
JTAG_TCK: DEBUG.2, JTAG.4, RN2.7 (2), U1.28 (PB28)
JTAG_TDI: JTAG.8, RN1.3 (1), U1.29 (PB29)
JTAG_TDO: JTAG.6, U1.30 (PB30)
JTAG_TMS: DEBUG.3, JTAG.2, RN2.6 (2), U1.31 (PB31)
L13: IC1.1 (OUT), IC1.2 (-IN), RN3.6 (2)
MASTER-RESET: C20.1, DEBUG.4, POWER.3, R1.2, R23.2, RESET.3, RESET.4, SPI.5, U1.47 (NRSTB)
MISO: SPI.1, U1.108 (PA25)
MISO2: IC6.17 ((PD0/MISO/PCINT3)PB3), ICSP1.1
MOSI: SPI.4, U1.109 (PA26)
MOSI2: IC6.16 ((PDI/MOSI/PCINT2)PB2), ICSP1.4
unnamed: IC6.26 ((PCINT10)PC4), R21.1
unnamed: L.A, RN3.3 (1)
unnamed: ON.A, RN3.4 (1)
unnamed: R15.2, RX1.A
unnamed: R8.2, U1.51 (TST)
unnamed: Q2.1 (B), R3.2, RN4.8 (2)
unnamed: R4.1, U1.53 (FWUP)
unnamed: R5.2, U1.43 (DFSDM)
unnamed: R6.2, U1.42 (DFSDP)
unnamed: R14.2, TX1.A
unnamed: RN3.1, RX.A
unnamed: RN3.2 (1), TX.A
PIN22: U1.1 (PB26), XIO.3
PIN23: U1.7 (PA14), XIO.4
PIN24: U1.8 (PA15), XIO.5
PIN25: U1.13 (PD0), XIO.6
PIN26: U1.14 (PD1), XIO.7
PIN27: U1.15 (PD2), XIO.8
PIN28: U1.16 (PD3), XIO.9
PIN29: U1.19 (PD6), XIO.10
PIN30: U1.22 (PD9), XIO.11
PIN31: U1.26 (PA7), XIO.12
PIN32: U1.32 (PD10), XIO.13
PIN33: U1.55 (PC1), XIO.14
PIN34: U1.59 (PC2), XIO.15
PIN35: U1.60 (PC3), XIO.16
PIN36: U1.116 (PC4), XIO.17
PIN37: U1.63 (PC5), XIO.18
PIN38: U1.64 (PC6), XIO.19
PIN39: U1.65 (PC7), XIO.20
PIN40: U1.66 (PC8), XIO.21
PIN41: U1.67 (PC9), XIO.22
PIN42: U1.71 (PA19), XIO.23
PIN43: U1.72 (PA20), XIO.24
PIN44: U1.101 (PC19), XIO.25
PIN45: U1.100 (PC18), XIO.26
PIN46: U1.99 (PC17), XIO.27
PIN47: U1.98 (PC16), XIO.28
PIN48: U1.97 (PC15), XIO.29
PIN49: U1.96 (PC14), XIO.30
PIN50: U1.95 (PC13), XIO.31
PIN51: U1.94 (PC12), XIO.32
PWM2: PWML.3, U1.144 (PB25)
PWM3: PWML.4, U1.139 (PC28)
PWM5: PWML.6, U1.136 (PC25)
PWM6: PWML.7, U1.135 (PC24)
PWM7: PWML.8, U1.134 (PC23)
PWM8: PWMH.1, U1.133 (PC22)
PWM9: PWMH.2, U1.132 (PC21)
PWM11: PWMH.4, U1.20 (PD7)
PWM12: PWMH.5, U1.21 (PD8)
PWM13: IC1.3 (+IN), PWMH.6, U1.68 (PB27)
RD+: IC6.29 (D+), R20.1
RD-: IC6.30 (D-), R19.1
RESET2: D2.A, IC6.24 (RESET(PC1/DW)), ICSP1.5, R13.1
RESETA: MACB.2
RESET_CMD: IC6.22 ((INT4/ICP1/CLK0)PC7), R23.1
RX: IC10.4 (O), PWML.1, U1.27 (PA8)
RXD0: COMMUNICATION.2, U1.18 (PD5)
RXD1: COMMUNICATION.4, U1.5 (PA12)
RXD2: COMMUNICATION.6, U1.3 (PA10)
RXL: RX.C, U1.103 (PC30)
RXL-U2: IC6.10 ((INT5/AIN3)PD4), RX1.C
SCK2: IC6.15 ((SCLK/PCINT1)PB1), ICSP1.3
SCL0-3: COMMUNICATION.8, RN5.7 (2), U1.87 (PB13)
SCL1: PWMH.10, U1.70 (PA18)
SDA0-3: COMMUNICATION.7, RN5.8 (2), U1.86 (PB12)
SDA1: PWMH.9, U1.9 (PA17)
SPCK: SPI.3, U1.110 (PA27)
SS0/PWM10: PWMH.3, U1.102 (PC29), U1.111 (PA28)
SS1/PWM4: PWML.5, U1.112 (PA29), U1.137 (PC26)
SS3: U1.142 (PB23)
SW: C42.2, D4.P$1 (K), IC2.6 (SW), L4.P$1 (1)
TX: IC6.8 ((RXD1/AIN1/INT2)PD2), PWML.2, U1.2 (PA9)
TXD0: COMMUNICATION.1, U1.17 (PD4)
TXD1: COMMUNICATION.3, U1.6 (PA13)
TXD2: COMMUNICATION.5, U1.4 (PA11)
TXL: TX.C, U1.107 (PA21)
TXL-U2: IC6.11 ((XCK/AIN4/PCINT12)PD5), TX1.C
UOTGID: U1.129 (PB11), USB1.4 (ID), Z5.2
UOTGVBOF: R3.1, U1.128 (PB10)
USBVCC: C27.+, C35.+, F1.1, R2.2, R21.2, T1.1 (D)
USBVCCU2: C28.1, F2.1, IC6.31 (UVCC), T2.1 (D)
VBG: C25.1, R7.2, U1.40 (VBG)
VDDANA: C3.+, C10.2, L1.2, U1.73 (VDDANA)
VDDOUT: C11.+, C12.2, C13.2, C14.2, C15.2, C16.2, C17.2, L5.1, U1.10 (VDDCORE1), U1.45 (VDDCORE2), U1.56 (VDDOUT), U1.61 (VDDCORE3), U1.104 (VDDCORE4), U1.124 (VDDCORE5)
VDDOUTMI: C2.+, C9.2, L2.2, U1.41 (VDDUTMI)
VDDPLL: C32.2, C33.+, L5.2, U1.34 (VDDPLL)
VIN: C41.+, IC2.5 (VIN), L6.1, PC1.+, POWER.8, R10.1, RN4.6 (2)
VIN+: D1.C, L6.2, X2.2
VUCAP: C38.1, IC6.27 (UCAP)
XIN: C22.1, U1.36 (XIN), Y1.1 (C1)
XIN32: C24.1, U1.48 (XIN32), Y2.P$2 (2)
XOUT: C21.1, U1.35 (XOUT), Y1.3 (C2)
XOUT32: C23.1, U1.49 (XOUT32), Y2.P$1 (1)
XT1: C39.1, IC6.1 (XTAL1), R9.1, Y4.1 (C1)
XT2: C40.1, IC6.2 (XTAL2(PC0)), R9.2, Y4.3 (C2)
XUSB: C26.1, F1.2, U1.39 (VBUS), USB1.1 (VUSB)
XVCC: F2.2, J3.P1 (VBUS)

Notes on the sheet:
TWI pullups
TWCK1
TWD1
IOREF
TWCK0
TWD0
AD1
AD2
AD3
AD4
AD5
AD6
AD0
USB AB
AREF
AD7
SD-CS
Forces OFF the power supply to USB port
when the USB port is in HOST mode
(board powered from external power supply)
N.C.
JTAG
ERASE
CONNECT
VBUSPO: VBus Polarity Off
0: The UOTGVBOF output signal is in its default mode (active high)
1: The UOTGVBOF output signal is inverted (active low)
ETH
UTXD
URXD
(ETH)
(SD)
ETH-CS
I2C Voltage Translator
USB boot En
IF LM2736Y
R2=1K
R3=330R
CONFIG 5V
USB B

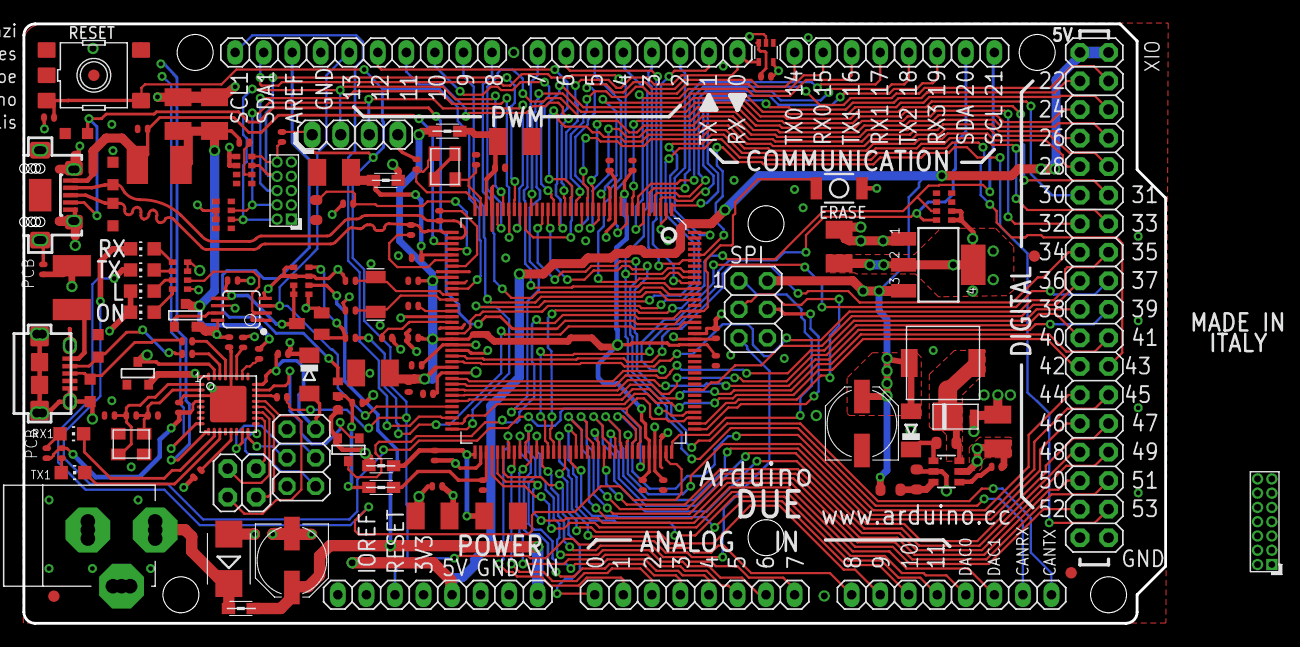
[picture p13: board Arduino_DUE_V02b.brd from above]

Board: 4 copper layers, 101.6 x 53.3 mm, 130 parts (0 on the bottom side), 149 nets.

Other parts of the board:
E$1: DISC

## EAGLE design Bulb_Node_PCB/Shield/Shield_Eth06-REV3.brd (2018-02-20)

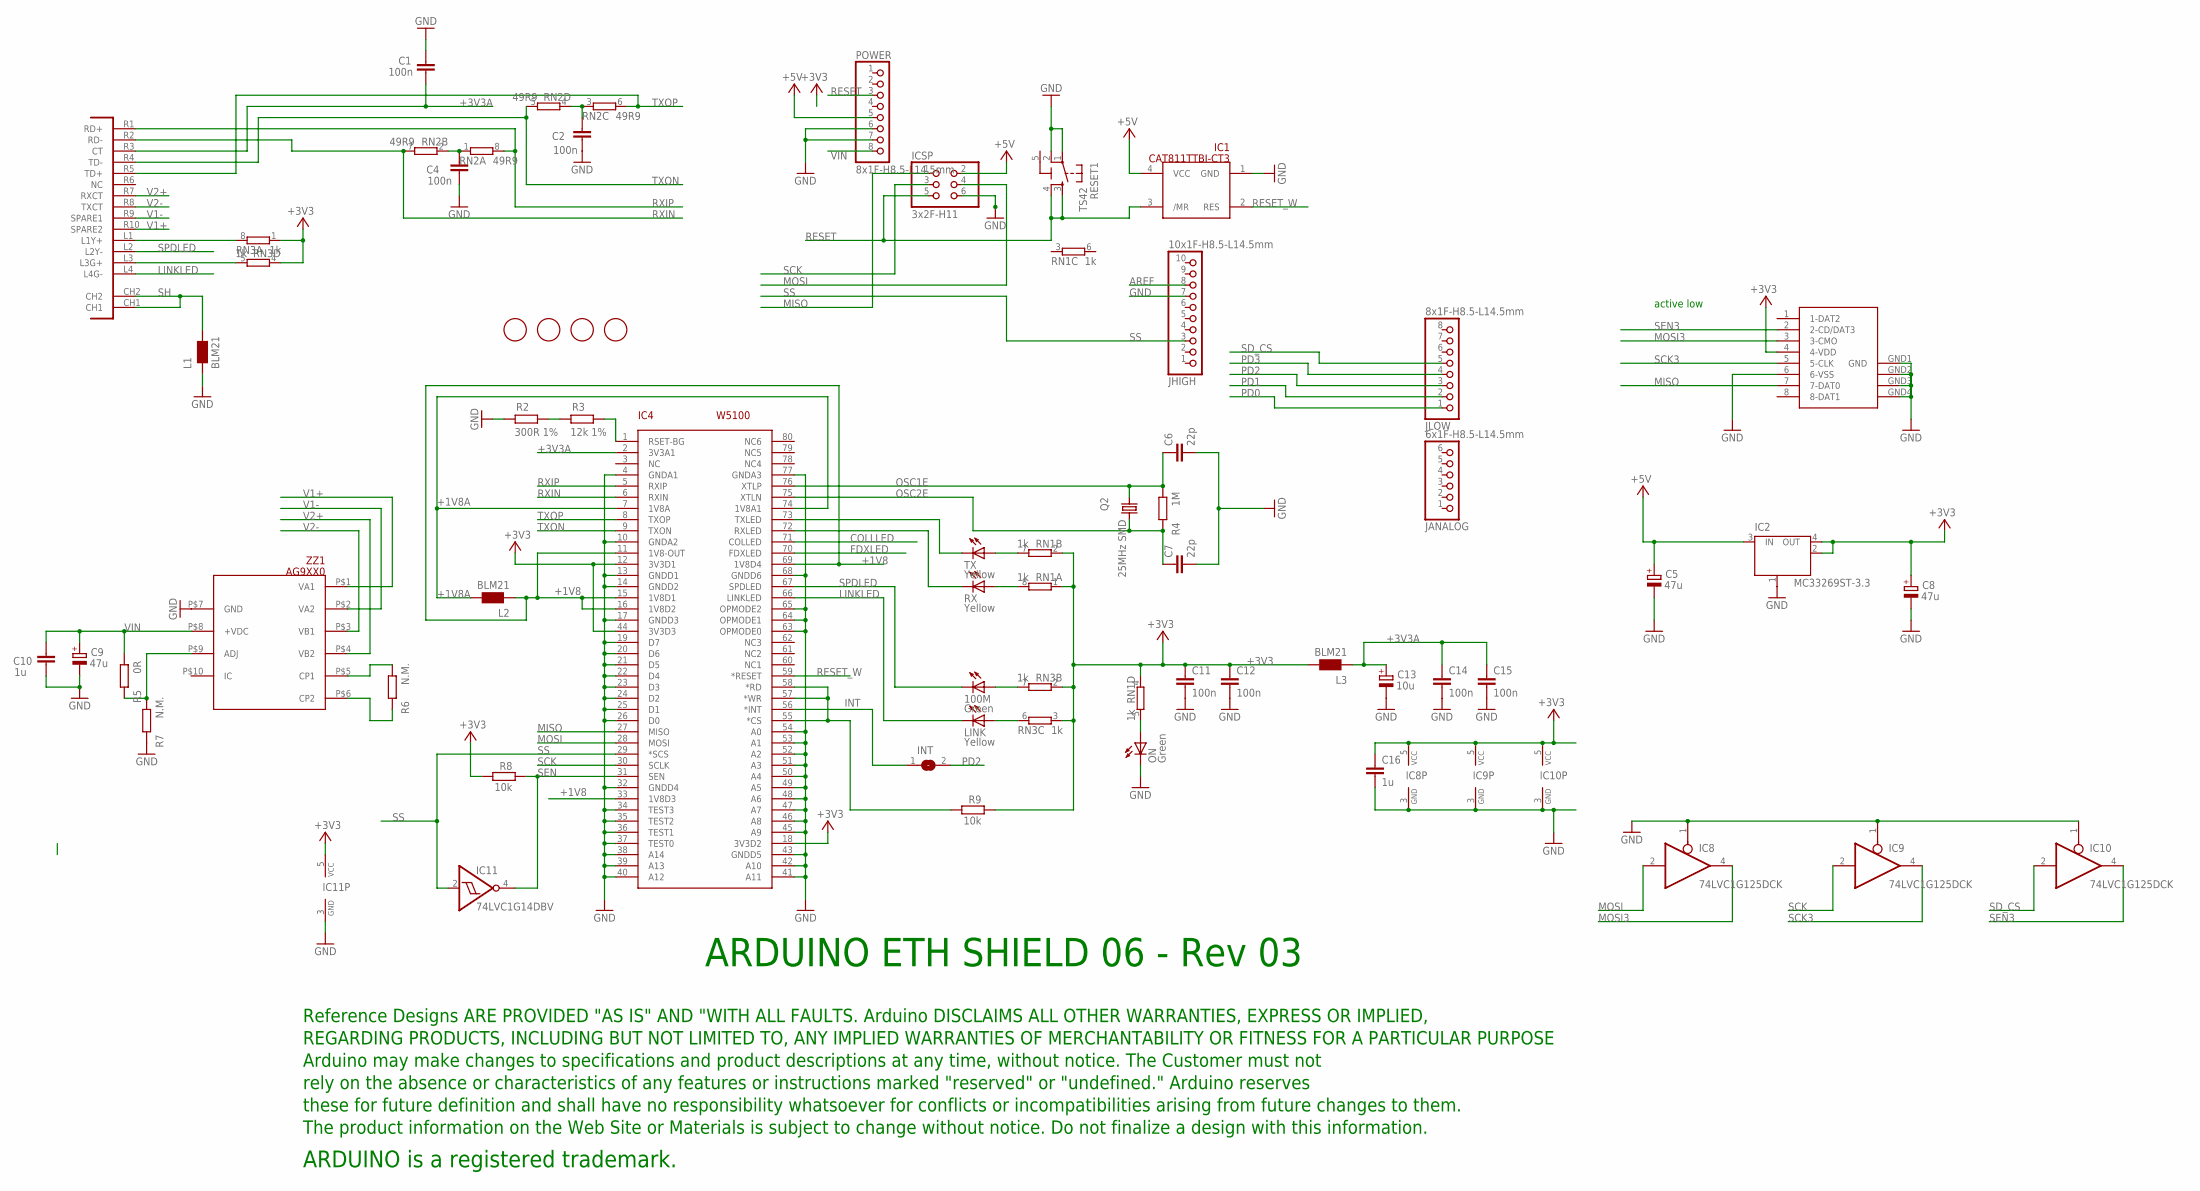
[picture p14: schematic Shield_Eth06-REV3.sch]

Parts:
100M: Green; CHIPLED_0805
C1, C2, C4, C11, C12, C14, C15: 100n; C0603-ROUND
C5, C8, C9: 47u; PANASONIC_D
C6, C7: 22p; C0603-ROUND
C10, C16: 1u; C0603-ROUND
C13: 10u; SMC_B
FID1, FID2, FID3, FID4: FIDUCIALMOUNT; FIDUCIA-MOUNT
IC1: CAT811TTBI-CT3; SOT143
IC2: MC33269ST-3.3; SOT223
IC4: W5100; SQFP-S-10X10-80
IC8, IC9, IC10: 74LVC1G125DCK; SC70-5
IC11: 74LVC1G14DBV; SOT23-5
ICSP: 3x2F-H11; 2X03
INT: SJ
JANALOG: 6x1F-H8.5-L14.5mm; 1X06
JHIGH: 10x1F-H8.5-L14.5mm; 1X10
JLOW: 8x1F-H8.5-L14.5mm; 1X08
L1, L2, L3: BLM21; 0805
LINK: Yellow; CHIPLED_0805
ON: Green; CHIPLED_0805
POWER: 8x1F-H8.5-L14.5mm; 1X08
Q2: 25MHz SMD; HC49UP
R2: 300R 1%; R0603-ROUND
R3: 12k 1%; R0603-ROUND
R4: 1M; R0603-ROUND
R5: 0R; R0603-ROUND
R6, R7: N.M.; R0603-ROUND
R8, R9: 10k; R0603-ROUND
RESET1: TS42
RN1, RN3: 1k; CAY16
RN2: 49R9; CAY16
RX: Yellow; CHIPLED_0805
TX: Yellow; CHIPLED_0805
U$1: POE-RJ45
U$2: DISCLAIMER
X1: SDCARD-15TW-8821
ZZ1: AG9XX0; AG9000

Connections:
5-GND: RESET1.5 (5-GND)
+1V8: IC4.11 (1V8-OUT), IC4.15 (1V8D1), IC4.16 (1V8D2), IC4.33 (1V8D3), IC4.69 (1V8D4), L2.1
+1V8A: IC4.7 (1V8A), IC4.74 (1V8A1), L2.2
+3V3: C8.+, C11.1, C12.1, C16.1, IC2.2 (OUT), IC2.4 (OUT), IC4.12 (3V3D1), IC4.18 (3V3D2), IC4.44 (3V3D3), IC8.5 (VCC), IC9.5 (VCC), IC10.5 (VCC), IC11.5 (VCC), L3.2, R8.1, R9.2, RN1.1, RN1.2 (1), RN1.4 (1), RN3.1, RN3.2 (1), RN3.3 (1), RN3.4 (1), X1.4 (4-VDD)
+3V3A: C1.1, C13.+, C14.1, C15.1, IC4.2 (3V3A1), L3.1, U$1.R3 (CT)
+5V: C5.+, IC1.4 (VCC), IC2.3 (IN), ICSP.2, POWER.5
AREF: JHIGH.8
COLLLED: IC4.71 (COLLED)
FDXLED: IC4.70 (FDXLED)
GND: C1.2, C2.1, C4.1, C5.-, C6.2, C7.2, C8.-, C9.-, C10.1, C11.2, C12.2, C13.-, C14.2, C15.2, C16.2, IC1.1 (GND), IC2.1 (GND/ADJ), IC4.4 (GNDA1), IC4.10 (GNDA2), IC4.13 (GNDD1), IC4.14 (GNDD2), IC4.17 (GNDD3), IC4.19 (D7), IC4.20 (D6), IC4.21 (D5), IC4.22 (D4), IC4.23 (D3), IC4.24 (D2), IC4.25 (D1), IC4.26 (D0), IC4.32 (GNDD4), IC4.34 (TEST3), IC4.35 (TEST2), IC4.36 (TEST1), IC4.37 (TEST0), IC4.38 (A14), IC4.39 (A13), IC4.40 (A12), IC4.41 (A11), IC4.42 (A10), IC4.43 (GNDD5), IC4.45 (A9), IC4.46 (A8), IC4.47 (A7), IC4.48 (A6), IC4.49 (A5), IC4.50 (A4), IC4.51 (A3), IC4.52 (A2), IC4.53 (A1), IC4.54 (A0), IC4.63 (OPMODE0), IC4.64 (OPMODE1), IC4.65 (OPMODE2), IC4.68 (GNDD6), IC4.77 (GNDA3), IC8.1 (OE), IC8.3 (GND), IC9.1 (OE), IC9.3 (GND), IC10.1 (OE), IC10.3 (GND), IC11.3 (GND), ICSP.6, JHIGH.7, L1.1, ON.C, POWER.6, POWER.7, R2.2, R7.2, RESET1.1, RESET1.2, X1.6 (6-VSS), X1.GND1 (GND), X1.GND2 (GND1), X1.GND3 (GND2), X1.GND4 (GND3), ZZ1.P$7 (GND)
INT: IC4.56 (*INT), INT.1
LINKLED: IC4.66 (LINKLED), LINK.C, U$1.L4 (L4G-)
MISO: IC4.27 (MISO), ICSP.1, X1.7 (7-DAT0)
MOSI: IC4.28 (MOSI), IC8.2 (I), ICSP.4
MOSI3: IC8.4 (O), X1.3 (3-CMO)
unnamed: RN3.5 (2), U$1.L3 (L3G+)
unnamed: RN3.8 (2), U$1.L1 (L1Y+)
unnamed: IC4.73 (TXLED), TX.C
unnamed: IC4.72 (RXLED), RX.C
unnamed: ON.A, RN1.5 (2)
unnamed: RN1.7 (2), TX.A
unnamed: C2.2, RN2.3 (1), RN2.4 (1)
unnamed: RN1.8 (2), RX.A
unnamed: 100M.A, RN3.7 (2)
unnamed: LINK.A, RN3.6 (2)
unnamed: C4.2, RN2.1, RN2.2 (1)
unnamed: R2.1, R3.2
unnamed: IC4.1 (RSET-BG), R3.1
unnamed: R6.1, ZZ1.P$5 (CP1)
unnamed: R6.2, ZZ1.P$6 (CP2)
unnamed: R5.2, R7.1, ZZ1.P$9 (ADJ)
unnamed: IC4.55 (*CS), IC4.57 (*WR), IC4.58 (*RD), R9.1
OSC1E: C6.1, IC4.76 (XTLP), Q2.1, R4.1
OSC2E: C7.1, IC4.75 (XTLN), Q2.2, R4.2
PD0: JLOW.1
PD1: JLOW.2
PD2: INT.2, JLOW.3
PD3: JLOW.4
RESET: IC1.3 (/MR), ICSP.5, POWER.3, RESET1.3, RESET1.4
RESET_W: IC1.2 (RES), IC4.59 (*RESET)
RXIN: IC4.6 (RXIN), RN2.7 (2), U$1.R2 (RD-)
RXIP: IC4.5 (RXIP), RN2.8 (2), U$1.R1 (RD+)
SCK: IC4.30 (SCLK), IC9.2 (I), ICSP.3
SCK3: IC9.4 (O), X1.5 (5-CLK)
SD_CS: IC10.2 (I), JLOW.5
SEN: IC4.31 (SEN), IC11.4 (O), R8.2
SEN3: IC10.4 (O), X1.2 (2-CD/DAT3)
SH: L1.2, U$1.CH1, U$1.CH2
SPDLED: 100M.C, IC4.67 (SPDLED), U$1.L2 (L2Y-)
SS: IC4.29 (*SCS), IC11.2 (I), JHIGH.3
TXON: IC4.9 (TXON), RN2.5 (2), U$1.R4 (TD-)
TXOP: IC4.8 (TXOP), RN2.6 (2), U$1.R5 (TD+)
V1+: U$1.R10 (SPARE2), ZZ1.P$1 (VA1)
V1-: U$1.R9 (SPARE1), ZZ1.P$2 (VA2)
V2+: U$1.R7 (RXCT), ZZ1.P$4 (VB2)
V2-: U$1.R8 (TXCT), ZZ1.P$3 (VB1)
VIN: C9.+, C10.2, POWER.8, R5.1, ZZ1.P$8 (+VDC)

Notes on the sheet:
ARDUINO ETH SHIELD 06 - Rev 03
active low

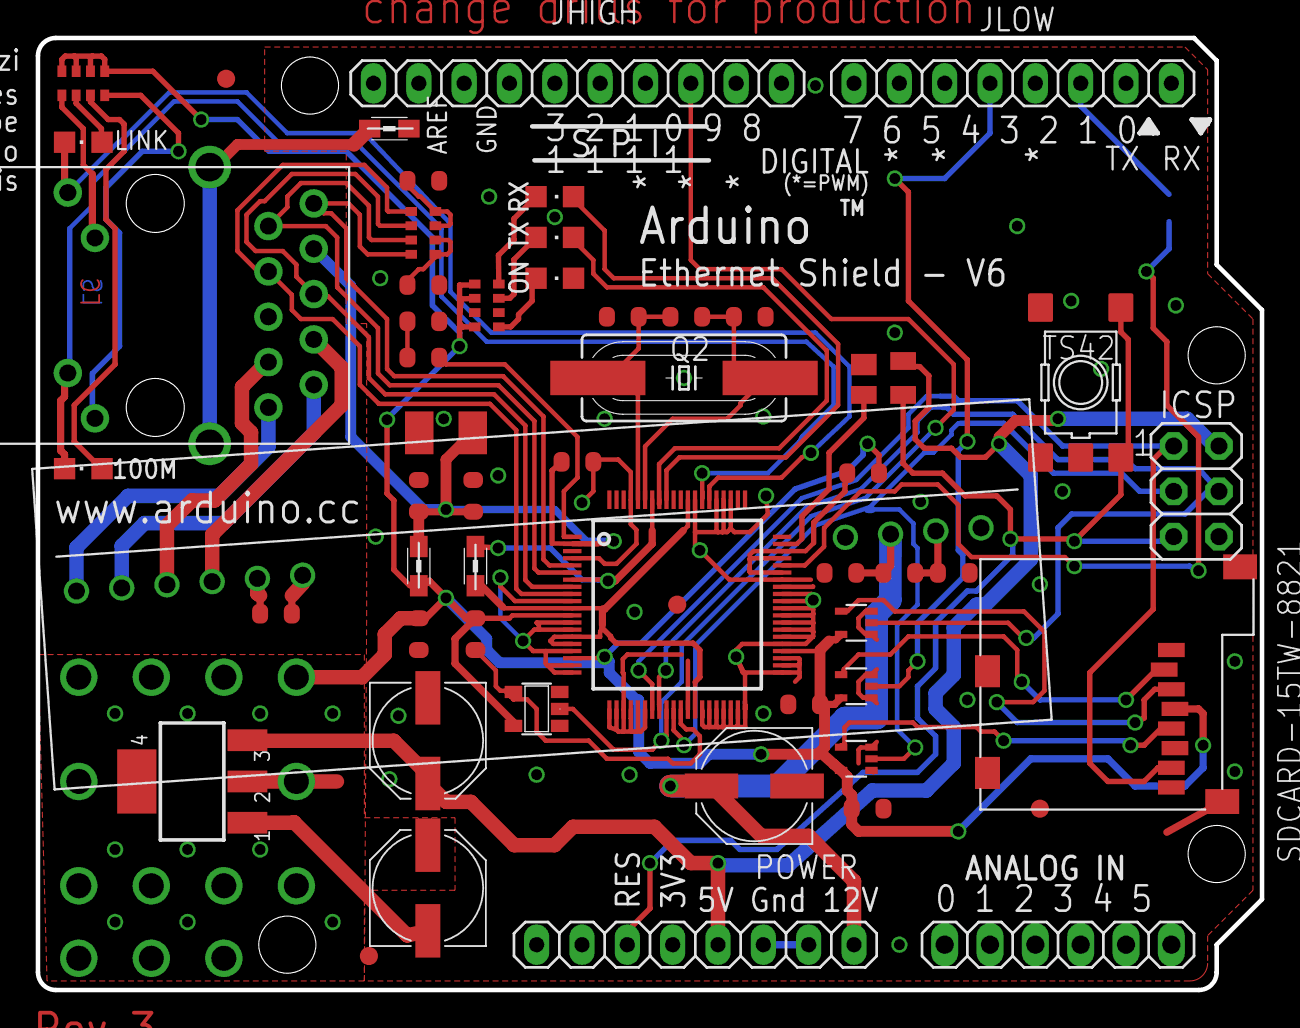
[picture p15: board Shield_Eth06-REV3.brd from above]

Board: 2 copper layers, 68.6 x 53.3 mm, 57 parts (1 on the bottom side), 50 nets.

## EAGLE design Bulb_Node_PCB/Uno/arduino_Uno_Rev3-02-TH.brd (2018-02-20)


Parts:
AD: 6x1F-H8.5; 1X06
C1, C2, C4, C5, C6, C7: 100n; C0603-ROUND
C3, C8: 1u; C0603-ROUND
C9, C11: 22p; C0603-ROUND
D1: M7; SMB
D2, D3: CD1206-S01575; MINIMELF
F1: MF-MSMF050-2 500mA; L1812
FD1, FD2, FD3: FIDUCIALMOUNT; FIDUCIA-MOUNT
GROUND: SJ
ICSP, ICSP1: 3x2 M; 2X03
IOH: 10x1F-H8.5; 1X10
IOL: 8x1F-H8.5; 1X08
JP2: 2x2 M - NM; 2X02
L: YELLOW; CHIP-LED0805
L1: BLM21; 0805
ON: GREEN; CHIP-LED0805
PC1, PC2: 47u; PANASONIC_D
POWER: 8x1F-H8.5; 1X08
R1, R2: 1M; R0603-ROUND
RESET: TS42031-160R-TR-7260; TS42
RESET-EN: SJ
RN1: 10K; CAY16
RN2, RN4: 1K; CAY16
RN3: 22R; CAY16
RX: YELLOW; CHIP-LED0805
T1: FDN340P; SOT-23
TX: YELLOW; CHIP-LED0805
U1: NCP1117ST50T3G; SOT223
U2: LP2985-33DBVR; SOT23-DBV
U3: ATMEGA16U2-MU(R); MLF32
U5: LMV358IDGKR; MSOP08
U$1: DISCLAIMER
X1: POWERSUPPLY_DC21MMX; POWERSUPPLY_DC-21MM
X2: USB-B_TH; PN61729
Y1: 16MHz; QS
Y2: CSTCE16M0V53-R0 16MHZ; RESONATOR
Z1, Z2: CG0603MLC-05E; CT/CN0603
ZU4: ATMEGA328P-PU; DIL28-3

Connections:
5-GND: RESET.5 (5-GND)
+3V3: C3.2, POWER.4, U2.5 (OUT), U5.2 (-IN)
+5V: C1.2, C2.2, C6.2, C7.1, D2.C, D3.C, ICSP.2, ICSP1.2, PC2.+, POWER.2, POWER.5, RN1.3 (1), RN1.5 (2), RN2.2 (1), RN2.3 (1), RN4.3 (1), RN4.4 (1), T1.2 (S), U1.2 (OUT), U1.4 (OUT), U2.1 (IN), U2.3 (ON/!OFF), U3.4 (VCC), U3.32 (AVCC), U5.8 (V+), ZU4.7 (VCC), ZU4.20 (AVCC)
AD0: AD.1, ZU4.23 ((ADC0)PC0))
AD1: AD.2, ZU4.24 ((ADC1)PC1)
AD2: AD.3, ZU4.25 ((ADC2)PC2)
AD3: AD.4, ZU4.26 ((ADC3)PC3)
AD4/SDA: AD.5, IOH.9, ZU4.27 ((ADC4)PC4)
AD5/SCL: AD.6, IOH.10, ZU4.28 ((ADC5)PC5)
AREF: C4.2, IOH.8, ZU4.21 (AREF)
CMP: RN1.1, RN1.2 (1), U5.3 (+IN)
D+: RN3.5 (2), X2.3, Z1.1
D-: RN3.8 (2), X2.2, Z2.1
DTR: C5.1, RN2.4 (1), U3.13 ((CTS/HWB/AIN6/TO/INT7)PD7)
GATE_CMD: T1.3 (G), U5.1 (OUT)
GND: C1.1, C2.1, C3.1, C4.1, C6.1, C7.2, C9.2, C11.2, GROUND.1, ICSP.6, ICSP1.6, IOH.7, L.C, ON.C, PC1.-, PC2.-, POWER.6, POWER.7, RESET.1, RESET.2, RN1.7 (2), RN2.5 (2), U1.1 (GND/ADJ), U2.2 (GND), U3.3 (GND), U3.33 (PAD), U5.4 (V-), X1.1, X1.3, Y2.2, ZU4.8 (GND), ZU4.22 (AGND)
IO0: IOL.1, RN4.2 (1), ZU4.2 ((RXD)PD0)
IO1: IOL.2, RN4.1, ZU4.3 ((TXD)PD1)
IO2: IOL.3, ZU4.4 ((INT0)PD2)
IO3: IOL.4, ZU4.5 ((INT1)PD3)
IO4: IOL.5, ZU4.6 ((T0)PD4)
IO5: IOL.6, ZU4.11 ((T1)PD5)
IO6: IOL.7, ZU4.12 ((AIN0)PD6)
IO7: IOL.8, ZU4.13 ((AIN1)PD7)
IO8: IOH.1, ZU4.14 ((ICP)PB0)
IO9: IOH.2, ZU4.15 ((OC1)PB1)
L13: RN2.8 (2), U5.6 (-IN), U5.7 (OUT)
M8RXD: RN4.7 (2), U3.9 ((TXD1/INT3)PD3)
M8TXD: RN4.8 (2), U3.8 ((RXD1/AIN1/INT2)PD2)
MISO: ICSP.1, IOH.5, ZU4.18 ((MISO)PB4)
MISO2: ICSP1.1, U3.17 ((PD0/MISO/PCINT3)PB3)
MOSI: ICSP.4, IOH.4, ZU4.17 ((MOSI)PB3)
MOSI2: ICSP1.4, U3.16 ((PDI/MOSI/PCINT2)PB2)
unnamed: L.A, RN2.1
unnamed: ON.A, RN4.5 (2), RN4.6 (2)
unnamed: RN2.7 (2), RX.A
unnamed: RN2.6 (2), TX.A
PB4: JP2.1, U3.18 ((T1/PCINT4)PB4)
PB5: JP2.3, U3.19 ((PCINT5)PB5)
PB6: JP2.2, U3.20 ((PCINT6)PB6)
PB7: JP2.4, U3.21 ((PCINT7/OC0A/OC1C)PB7)
PWRIN: D1.A, X1.2
RD+: RN3.4 (1), U3.29 (D+)
RD-: RN3.1, U3.30 (D-)
RESET: C5.2, D2.A, ICSP.5, POWER.3, RESET.3, RESET.4, RESET-EN.1, RESET-EN.2, RN1.4 (1), ZU4.1 (RESET)
RESET2: D3.A, ICSP1.5, RN1.6 (2), U3.24 (RESET(PC1/DW))
RXLED: RX.C, U3.10 ((INT5/AIN3)PD4)
SCK: ICSP.3, IOH.6, U5.5 (+IN), ZU4.19 ((SCK)PB5)
SCK2: ICSP1.3, U3.15 ((SCLK/PCINT1)PB1)
SS: IOH.3, ZU4.16 ((SS)PB2)
TP_VUCAP: C8.1, U3.27 (UCAP)
TXLED: TX.C, U3.11 ((XCK/AIN4/PCINT12)PD5)
UGND: C8.2, GROUND.2, L1.1, U3.28 (UGND), X2.4
USBVCC: F1.1, T1.1 (D), U3.31 (UVCC)
USHIELD: L1.2, X2.P$1, X2.P$2, Z1.2, Z2.2
VIN: D1.C, PC1.+, POWER.8, RN1.8 (2), U1.3 (IN)
XT1: C9.1, R1.1, U3.1 (XTAL1), Y1.2
XT2: C11.1, R1.2, U3.2 (XTAL2(PC0)), Y1.1
XTAL1: R2.1, Y2.3, ZU4.9 (XTAL1)
XTAL2: R2.2, Y2.1, ZU4.10 (XTAL2)
XUSB: F1.2, X2.1

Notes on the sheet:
Arduino(TM) UNO Rev3
USB boot En
SDA
SCL
Use of the ARDUINO name must be compliant with http://www.arduino.cc/en/Main/Policy


Board: 2 copper layers, 68.6 x 53.3 mm, 53 parts (1 on the bottom side), 60 nets.

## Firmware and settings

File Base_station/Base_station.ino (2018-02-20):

#include <VirtualWire.h>
#include <EEPROM.h>
#include <SPI.h>        
#include <Ethernet.h>
#include <EthernetUdp.h> 

#define REPEAT 3
#define CLOCK 100
#define WAIT 600
#define LEDpin 8
#define PRINTTHETIME false

#define LEDHEADER 0x90
#define SOLID     0x01
#define STROBE    0x02
#define PULSE     0x03
#define FADE      0x04
#define AMBIANCE  0x05
#define MUSIC     0x06

byte mac[] = { 0xDE, 0xAD, 0xBE, 0xEF, 0xFE, 0xED };
IPAddress ip(10, 0, 0, 99);
unsigned int localPort = 8888; 
char  ReplyBuffer[] = "Packet Recieved"; 
const int NTP_PACKET_SIZE= 48; // NTP time stamp is in the first 48 bytes of the message
const int UDP_PACKET_SIZE= 48; // NTP time stamp is in the first 48 bytes of the message
byte ntppacketBuffer[NTP_PACKET_SIZE];
byte packetBuffer[UDP_PACKET_SIZE]; 
EthernetUDP Udp;

byte storage[16][7];

unsigned long lastXmit  = 0,
			  lastTimeCheck = 0,
			  lastNotif = 0,
			  currentDay = 0,
			  currentHour = 0,
			  currentMinute = 0,
			  currentSecond = 0,
			  countDown = 0;

int txPin = 3,
	txPin_315 = 6,
	rxPin = 5;


bool alarmweek[] = {false,false,false,false,false,false,false},
	 notifyFlag  = false;
int alarmTime[2] = {EEPROM.read(100), EEPROM.read(101)}; // Hour : Minute : Days


IPAddress timeServer(132, 163, 4, 101); // time-a.timefreq.bldrdoc.gov NTP server
// IPAddress timeServer(132, 163, 4, 102); // time-b.timefreq.bldrdoc.gov NTP server
// IPAddress timeServer(132, 163, 4, 103); // time-c.timefreq.bldrdoc.gov NTP server

void setup() 
{
    Serial.begin(115200);

    byte days = EEPROM.read(102);    
	for(int i = 0; i < 7; i++)	
		alarmweek[i] = GetBit(days,i);

    vw_set_tx_pin(txPin);
    vw_set_rx_pin(rxPin);
    vw_setup(4800);       // Bits per sec
    vw_rx_start();  

    Ethernet.begin(mac,ip);
 	Udp.begin(localPort);
}

void loop() 
{
    uint8_t values[VW_MAX_MESSAGE_LEN];
    uint8_t buflen = VW_MAX_MESSAGE_LEN;

	if( Udp.parsePacket() ) // Check for UDP message
	{
		Udp.read(packetBuffer,UDP_PACKET_SIZE);
		
		switch(packetBuffer[0])
		{
			case 0xA1:
				sendLED( packetBuffer );
			break;
			case 0xA2:
				sendAC(packetBuffer[1], packetBuffer[2]);
			break;
			case 0xA3:				
				setAlarm();
			break;
			case 0xB1:				
				// Program groups
			break;

			default:
				getTime();		
				if(currentSecond < 10)		
					parseAlarm();
			break;
		}		
	}
	if( millis() - lastTimeCheck >= 10000 )
	{
		sendNTPpacket( timeServer );
		lastTimeCheck = millis();
	}
	if( vw_get_message( values, &buflen ) )
	{
		if( values[0] == 0xA4 )
			sendNotification( values[1] );
	}
	if( millis() - lastNotif >= 3400 )
	{
		if( notifyFlag )
			eraseNotif();
	}
}


	// Helper Functions \\ 

void sendLED( byte *packetBuffer )
{
	byte _buffer[7];
	_buffer[0] = LEDHEADER;
	for(int i=1; i<7; i++)
		_buffer[i] = packetBuffer[i+1]; // Recieve RGB values

	broadcast( _buffer, 7 );
}

void sendNotification( byte notif )
{
	byte _buffer[7];

	_buffer[0] = LEDHEADER;
	_buffer[1] = (byte) 3;
    switch( notif )
    {
      case 0x01: _buffer[2] = 0;   _buffer[3] = 255; _buffer[4] = 0;   break;
      case 0x02: _buffer[2] = 255; _buffer[3] = 0;   _buffer[4] = 0;   break;
      case 0x03: _buffer[2] = 0;   _buffer[3] = 0;   _buffer[4] = 255; break;
      case 0x04: _buffer[2] = 255; _buffer[3] = 255; _buffer[4] = 0;   break;
      case 0x05: _buffer[2] = 0;   _buffer[3] = 255; _buffer[4] = 255; break;
      case 0x06: _buffer[2] = 255; _buffer[3] = 0;   _buffer[4] = 255; break;
    }    
    _buffer[5] = (byte) 255;
    _buffer[6] = (byte) 25;

    notifyFlag = true;
    lastNotif = millis();

	broadcast( _buffer, 7 );
}

void broadcast( byte _buffer[7], int numBytes )
{
	for(int j = 0; j < REPEAT; j++)
	{
		vw_send((uint8_t *)_buffer, numBytes);
		vw_wait_tx(); 
	}

	if(numBytes == 8 && notifyFlag == false)
		for(int i=0; i<7; i++)
		{
			EEPROM.write(i, _buffer[i]);
			storage[0][i] = _buffer[i];
		}

	lastXmit = millis();
}

void eraseNotif()
{
	byte _buffer[7];
	_buffer[0] = LEDHEADER;
	notifyFlag = false;
	for(int i =1; i<7; i++)
		_buffer[i] = storage[0][i];
	broadcast(_buffer, 7);
}

unsigned long sendNTPpacket(IPAddress& address)
{
  // set all bytes in the buffer to 0
  memset(ntppacketBuffer, 0, NTP_PACKET_SIZE); 
  // Initialize values needed to form NTP request
  // (see URL above for details on the packets)
  ntppacketBuffer[0] = 0b11100011;   // LI, Version, Mode
  ntppacketBuffer[1] = 0;     // Stratum, or type of clock
  ntppacketBuffer[2] = 6;     // Polling Interval
  ntppacketBuffer[3] = 0xEC;  // Peer Clock Precision
  // 8 bytes of zero for Root Delay & Root Dispersion
  ntppacketBuffer[12]  = 49; 
  ntppacketBuffer[13]  = 0x4E;
  ntppacketBuffer[14]  = 49;
  ntppacketBuffer[15]  = 52;

  // all NTP fields have been given values, now
  // you can send a packet requesting a timestamp:         
  Udp.beginPacket(address, 123); //NTP requests are to port 123
  Udp.write(ntppacketBuffer,NTP_PACKET_SIZE);
  Udp.endPacket(); 
}

void setAlarm()
{
	alarmTime[0] = packetBuffer[1];
	alarmTime[1] = packetBuffer[2];
	byte days    = packetBuffer[3];

	for(int i = 0; i < 7; i++)
		alarmweek[i] = GetBit(days, i);

	EEPROM.write(100, alarmTime[0]);
	EEPROM.write(101, alarmTime[1]);
	EEPROM.write(102, days);
}

void parseAlarm()
{
	bool flag = false;
	byte _buffer[7];

	_buffer[0] = LEDHEADER;

	for(int i = 0; i<7; i++)
		flag = flag || ( currentDay && alarmweek[i] );

	if( flag )
	{
		if( mintillAlarm() == 30 )
		{
			_buffer[1] = SOLID;
			_buffer[2] = 0x00;
			_buffer[3] = 0xFF;
			_buffer[4] = 0x00;
			_buffer[5] = (byte) 255*1/4;
			_buffer[6] = 0xFF;
			broadcast(_buffer, 7);
		} else if ( mintillAlarm() == 20 )
		{
			_buffer[1] = SOLID;
			_buffer[2] = 0xFF;
			_buffer[3] = 0xFF;
			_buffer[4] = 0x00;
			_buffer[5] = (byte) 255*2/4;
			_buffer[6] = 0xFF;
			broadcast(_buffer, 7);
		} else if ( mintillAlarm() == 10 )
		{
			_buffer[1] = SOLID;
			_buffer[2] = 0xFF;
			_buffer[3] = 0x00;
			_buffer[4] = 0x00;
			_buffer[5] = (byte) 255*3/4;
			_buffer[6] = 0xFF;
			broadcast(_buffer, 7);

		} else if ( mintillAlarm() == 0 )
		{	
			_buffer[1] = STROBE;
			_buffer[2] = 0xFF;
			_buffer[3] = 0xFF;
			_buffer[4] = 0xFF;
			_buffer[5] = (byte) 255;
			_buffer[6] = 0x7F;
			broadcast(_buffer, 7);
			sendAC(0x01,true);
			sendAC(0x02,true);
			sendAC(0x03,true);
			sendAC(0x04,true);
		} else if ( mintillAlarm() == 1435 )
		{
			// return to previous state
			for(int i =1; i<7; i++)
				_buffer[i] = storage[0][i];
			broadcast(_buffer, 7);
		}
	}
}

int mintillAlarm()
{
	int minCurrent = currentHour*60 + currentMinute;
	int minAlarm   = alarmTime[0]*60 + alarmTime[1];

	if( minAlarm >= minCurrent )
		return minAlarm - minCurrent;
	else
		return 1440 - minCurrent + minAlarm;
}

void getTime()
{
	unsigned long highWord = word(packetBuffer[40], packetBuffer[41]);
    unsigned long lowWord = word(packetBuffer[42], packetBuffer[43]);  
    // combine the four bytes (two words) into a long integer
    // this is NTP time (seconds since Jan 1 1900):
    unsigned long secsSince1900 = highWord << 16 | lowWord;        

    // now convert NTP time into everyday time:
    // Unix time starts on Jan 1 1970. In seconds, that's 2208988800:
    const unsigned long seventyYears = 2208988800UL;     
    // subtract seventy years:
    unsigned long epoch = secsSince1900 - seventyYears;                     

    currentDay = (epoch / 86400L) % 7;

    if((epoch  % 86400L) / 3600 < 5)
    	currentHour = (epoch  % 86400L) / 3600 + 19;
	else
    	currentHour = (epoch  % 86400L) / 3600 - 5;
    currentMinute = (epoch  % 3600) / 60;
    currentSecond = epoch %60;

    if( PRINTTHETIME )
    {
	    // print the hour, minute and second:
	    Serial.print("The CST time is ");       // UTC is the time at Greenwich Meridian (GMT)
	    Serial.print(currentHour); // print the hour (86400 equals secs per day)
	    Serial.print(':');  
	    if ( currentHour < 10 ) {
	      // In the first 10 minutes of each hour, we'll want a leading '0'
	      Serial.print('0');
	    }
	    Serial.print(currentMinute); // print the minute (3600 equals secs per minute)
	    Serial.print(':'); 
	    if ( currentMinute < 10 ) {
	      // In the first 10 seconds of each minute, we'll want a leading '0'
	      Serial.print('0');
	    }
	    Serial.println(currentSecond); // print the second

	    Serial.print("Alarm set for ");
	    if ( alarmTime[0] < 10 ) {
	      // In the first 10 seconds of each minute, we'll want a leading '0'
	      Serial.print('0');
	    }
	    Serial.print(alarmTime[0]);
	    Serial.print(":");
	    if ( alarmTime[1] < 10 ) {
	      // In the first 10 seconds of each minute, we'll want a leading '0'
	      Serial.print('0');
	    }
	    Serial.println(alarmTime[1]);
	}
}

	// Functions for 315 MHz AC Relay \\

void sendAC(byte light, bool val)
{
  	byte head = 0;
    pinMode(txPin_315, OUTPUT);

  	switch(light)
	{
	  case 0x01: head = 0x0A; break;
	  case 0x02: head = 0x02; break; 
	  case 0x03: head = 0x08; break; 
	  case 0x04: head = 0x00; break;
	  default: head = 0x0F; break;
	}

  	if( val )
  	{
	    for(int i=0; i<10; i++)
	    {   
			// A->1010 B->0010 C->1000 D->0000
			for(int i = 4; i>=0; i--)
				sendBit(GetBit(head,i));

			// 10 1010 1100 0000 = 0x2AC0
			byte body = 0x2AC0;

			// for(int i = 13; i>=0; i--)
			//   sendBit(GetBit(body,i));

			// 1010
			sendBit(1);
			sendBit(0);
			sendBit(1);
			sendBit(0);
			// 1011
			sendBit(1);
			sendBit(0);
			sendBit(1);
			sendBit(1);
			// 0000
			sendBit(0);
			sendBit(0);
			sendBit(0);
			sendBit(0);
			// 00
			sendBit(0);
			sendBit(0);

			digitalWrite(txPin_315, LOW);

			delay(10);
		}	
	}
	else
	{
		for(int i=0; i<10; i++)
		{ 
			// A->1010 B->0010 C->1000 D->0000
			for(int i = 4; i>=0; i--)
				sendBit(GetBit(head,i));

			byte body = 0x2A30;
			// for(int i = 13; i>=0; i--)
			//   sendBit(GetBit(body,i));

			// 1010
			sendBit(1);
			sendBit(0);
			sendBit(1);
			sendBit(0);
			// 1000
			sendBit(1);
			sendBit(0);
			sendBit(0);
			sendBit(0);
			// 1100
			sendBit(1);
			sendBit(1);
			sendBit(0);
			sendBit(0);
			// 00
			sendBit(0);
			sendBit(0);

			digitalWrite(txPin_315, LOW);

			delay(10);
		}
 	}

    pinMode(txPin_315, INPUT);
	lastXmit = millis();	
}

void sendBit(bool val)
{
    digitalWrite(txPin_315, val);
    delayMicroseconds(WAIT);
    digitalWrite(txPin_315, LOW);
    delayMicroseconds(CLOCK);
    digitalWrite(txPin_315, HIGH);
    delayMicroseconds(CLOCK);
}

bool GetBit(byte b, int bitNumber) 
{
   return (b & (1 << bitNumber)) != 0;
}

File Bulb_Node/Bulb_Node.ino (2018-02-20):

#define DEBUG

#include <ArduinoJson.h>
#include <FastLED.h>
#ifdef DEBUG
#include <SoftwareSerial.h>
#endif
// #include "LEDFunc.ino"

/*
LED NODE JSON Structure
{  
    "Properties": 
    {  
      "Dev-ID": "LEDNode - v01",  
      "UID":    00000001,  
      "Net-ID": 00000000,
      "NLEDs":25
    }, 
    "Network": 
    {  
      "SSID": "",
      "SSID-PW": "",
      "LAN-IP": "127.0.0.1"
    }, 
    "State": 
    {
      "Mode": 1,  
      "Red": 00000000,  
      "Green": 00000000,`
      "Blue": 00000000,  
      "Period": 00000000,  
      "Intensity": 00000000      
    } 
}  
*/

#define DEFAULT_TIMEOUT_PERIOD 2000
#define WIFI_RESET_PIN 10
#define LED_PIN 13
#define LED_COM_PIN 5
#define LED_CLK_PIN 6
#define N_LEDS 32
#define LED_FRAME_RATE 500

// LedStates
#define LS_SOLID  0
#define LS_PULSE  1
#define LS_STROB  2
#define LS_AMBIA  3
#define LS_HUEST  4

uint8_t LED_STATE = 4;
int HuePtr = 0;

uint32_t LastTramsmit = 0;
uint32_t LastFrame = 0;

uint8_t STREAMINGOVERRIDE = 1;

CRGB leds[N_LEDS];

StaticJsonBuffer<150> jsonBuffer;
JsonObject& root = jsonBuffer.createObject();
JsonObject& properties = root.createNestedObject("Properties");
JsonObject& state = root.createNestedObject("State");

String received = ""; 
char inBuffer[100];
int bytesinbuf = 0;

void parseUART()
{
  boolean message_Processed = false;

  while(Serial.available() > 0)
  {
    FastLED.delay(10);

    int numbytes = Serial.available();

    // Serial.println(numbytes, DEC);

    bytesinbuf += numbytes;

    Serial.readBytes(inBuffer, numbytes);
  }

  if(bytesinbuf > 0)
  {
    received = String(inBuffer);

    for(int i=0; i < 100; i++)
    {
      inBuffer[i] = NULL;          
    }

    bytesinbuf = 0;
    // Serial.println(received);
  }



  // while(Serial.available() > 0 && !message_Processed) 
  // { 
    // received.concat(char(Serial.read())); 
    // Serial.println("=======INCOMING=======");

 // Example Message: 
 // "+IPD,0,12:{"mode","1"}"

  if(received.indexOf("+IPD") > -1)
  {
    // #ifdef DEBUG
    Serial.println("=======INCOMING=======");
    Serial.println(received);
    // #endif

    // int start = millis();
    // FastLED.delay(50);

    int IPDStart = received.indexOf("+IPD");
    int CIDX1 = received.indexOf(',', IPDStart);
    int CIDX2 = received.indexOf(',', CIDX1 + 1);
    int CIDX3 = received.indexOf(':', CIDX2 + 1);

    // #ifdef DEBUG
    Serial.print("IDX1 = " + String(CIDX1));
    Serial.print(" - IDX2 = " + String(CIDX2));
    Serial.println(" - IDX3 = " + String(CIDX3));
    // // #endif

    int messageChannel = (received.substring(CIDX1 + 1, CIDX2)).toInt();
    int messageLength = received.substring(CIDX2 + 1, CIDX3).toInt();

    while(received.length() < messageLength)
    {
      if(Serial.available() > 0)
      {
        int numbytes = Serial.available();

        Serial.println(numbytes, DEC);

        bytesinbuf += numbytes;

        Serial.readBytes(inBuffer, numbytes);
      }

      if(bytesinbuf > 0)
      {
        received.concat(inBuffer);

        for(int i=0; i < 100; i++)
        {
          inBuffer[i] = NULL;          
        }

        bytesinbuf = 0;
        Serial.println(received);
      }      
    }

    String data = received.substring(CIDX3 + 1, CIDX3 + 1 + messageLength);



    // // String response = "Sup?";
    // // send("AT+CIPSEND=" + String(messageChannel) + "," + String(response.length()), DEFAULT_TIMEOUT_PERIOD, ">");
    // // send(response, DEFAULT_TIMEOUT_PERIOD, "OK");
    // // send("AT+CIPCLOSE", 0, "OK");
    
    // // #ifdef DEBUG
    Serial.println("messageChannel: " + String(messageChannel));
    Serial.println("messageLength: " + String(messageLength));
    Serial.println("data: " + String(data));
    // // #endif

    // message_Processed = true;

    int datalength = data.length()+1;
    char char_data[datalength];

    for(int i=0; i<datalength; i++)
    {
      char_data[i] = ' ';
    }

    data.toCharArray(char_data, datalength);
    // Parse incoming JSON object
    JsonObject& inroot = jsonBuffer.parseObject(char_data);

    for(int i=0; i<datalength; i++)
    {
        Serial.print(char_data[i]);
    }
    Serial.println("");

    if(inroot.success())
    {
      for (JsonObject::iterator it=inroot.begin(); it!=inroot.end(); ++it)
      {
        if(state.containsKey(it->key))
        {
          state[it->key] = it->value;
        }
        // #ifdef DEBUG
        Serial.println(it->key);
        Serial.println(String(it->value.asString()));
        // #endif
      }
      // #ifdef DEBUG
      root.prettyPrintTo(Serial);
      // #endif
    }

    // #ifdef DEBUG
    Serial.println("=======EOM=======");
    // #endif

    received = "";
  } 

  // FastLED.delay(1);
  // }
}

void setup() 
{
  // Initialize Serial information
  Serial.begin(9600);

  Serial.println("Hello.");

  // send("AT+CIOBAUD?", DEFAULT_TIMEOUT_PERIOD, "OK");
  // send("AT+CIOBAUD=115200", DEFAULT_TIMEOUT_PERIOD, "OK");

  // Setup pins
  pinMode(LED_PIN, OUTPUT);
  pinMode(WIFI_RESET_PIN, OUTPUT);


  /*********************************/
  /*          JSON SETUP           */
  /*********************************/
  properties["Dev-ID"] = "LEDNode-v01";
  properties["UID"] = "0";
  properties["Net-ID"] = "0";
  properties["NLEDs"] = String(N_LEDS);

  state["Mode"] = "0";  
  state["Red"] = "0";  
  state["Green"] = "100";
  state["Blue"] = "255";  
  state["Period"] = "10000";  
  state["Intensity"] = "255";   
  state["huewidth"] = "175";  
  // #ifdef DEBUG
  root.prettyPrintTo(Serial);
  // #endif

  /*********************************/
  /*         Setup LED array       */
  /*********************************/
  // FastLED.addLeds<WS2812B, LED_COM_PIN, GRB>(leds, N_LEDS); 
  FastLED.addLeds<WS2801, LED_COM_PIN, LED_CLK_PIN, RGB>(leds, N_LEDS);

  // connectAP(ss, spw);

  // while(!send("AT+CIPSERVER=1,8080", DEFAULT_TIMEOUT_PERIOD, "OK"))
  // {
  //   reset();
  //   connectAP(ss, spw);
  //   FastLED.delay(50);
  // }
  // send("AT+CIFSR", DEFAULT_TIMEOUT_PERIOD, "OK");
}

uint8_t leapframes = 0;
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

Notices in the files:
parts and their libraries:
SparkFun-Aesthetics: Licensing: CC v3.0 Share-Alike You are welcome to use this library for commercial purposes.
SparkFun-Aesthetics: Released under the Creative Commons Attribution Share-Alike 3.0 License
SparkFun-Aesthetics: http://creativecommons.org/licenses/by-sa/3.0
